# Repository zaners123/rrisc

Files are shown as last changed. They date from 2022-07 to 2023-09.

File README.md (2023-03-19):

# RRISC (Reduced Reduced Instruction Set Computer)

My primary goal for this project was to make a computer from "scratch"
(simple logic gates and memory, no embedded microcontrollers/FPGAs/etc) to learn more about Computer Engineering
as a "learn by doing" approach.

Since it's only made out of simple logic gates and hand-soldered, it needs to be simple in design
(no microcode/pipelining) and in implementation (trying to aim for around 50 logic chips,
none of which are more complex than a comparator).

This project includes the Assembler, LogiSim simulator/emulator, schematic, and PCB.
This is the computer at every level of abstraction, and as such this is Open Source Hardware.

## What is RISC? What does this computer do? 

A RISC computer commonly has simple operations to have higher instructions per second.
My computer has extremely simple operations to have extreme efficiency (ideally).
My goal for this computer is for it to run at about 20MHz.

This is a General Purpose Von-Neumann-Architecture computer with 8-bit instructions.
It has 64Kb of RAM and all 16 instructions follow a quick 3-stage IF/EX/WB cycle.

Instructions are broken up into two parts. Here's the entire **Instruction Set Architecture**:

 ID | Opcode |  Description           |  Argument Type
----|--------|------------------------|-------------------------
 _  | 4 bits | _                      | 4 bits
0x0 | ADD    | Add to R0              | Register(1)
0x1 | ADDI   | Add to R0              | Immediate(2)       
0x2 | SUB    | Subtract from R0       | Register(1)   
0x3 | SUBI   | Subtract from R0       | Immediate(2)  
0x4 | SKIP   | Skip next instruction  | Condition(3)  
0x5 | JUMP   | Jump to MEM            | Condition(3)  
0x6 | XOR    | Xor                    | Register(1)        
0x7 | XORI   | Xor                    | Immediate(2)       
0x8 | AND    | And                    | Register(1)        
0x9 | ANDI   | And                    | Immediate(2)       
0xA | SET    | Move ACC to Reg        | Register(1)
0xB | RB     | Read from memory to Reg| Register(1)
0xC | GET    | Move Reg to ACC        | Register(1)
0xD | WB     | Write from reg to memory|Register(1)
0xE | OR     |                        |
0xF | ORI    |                        |

## Register(1)
The last 4 bits of this argument point to one of the 16 registers.

ACC (AKA R0) is the accumulator register.

R1-RC General Purpose Registers.

RMH,RML point in memory (Register Memory High, Register Memory Low).

RCMP is used in conditional operations<sup>[3](3)</sup>

## Immediate(2)

## Condition(3)

# Assembler

Given an assembly file (Ex: code.asm), it turns it into a hex file (Ex: code.asm.hex) that can be loaded either onto
the real computer, or the simulated computer in LogiSim.

# Simulation

This represents the computer's overall layout. It is both a logical diagram for the computer and a convenient simulator for programs.

Open this with Logisim Evolution. I use "logisim-evolution-3.4.1-all.jar".
Upload the hex from the assembler into the RAM, start the controller, and watch it run!

# Hardware

The strict hardware requirement of this computer is that everything except the memory-mapped-IO has to be made from 7400 logic.

This is made in KiCad, and contains the schematic (local layout of how things connect)
and the PCB design (how to physically connect everything together).

The plan is to have the submodules used in LogiSim (registers, ALU, RAM, etc) be a daughter board for the main PCB.

The plan is to design/order/build the PCBs in this order:
1. Program Counter
    - Logic for jump/skip decisions
2. Registers
    - Might use either a literal register file (select MUX, asynchronous D-latch, 8x 16:1 demux) or a 74xx register file 
3. ALU
4. RAM/ROM/Programmer
5. Motherboard/Controller
6. Memory-Mapped IO
    - Memory Mapped UART
    - Memory Mapped 7-segment Display

This way, I can test them all separately, and revisions can be made more easily.

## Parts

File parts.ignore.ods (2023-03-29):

Name | ID | QTY_HAVE | QTY_MOBO | QTY_ALU | Leftover
NAND | 0 | 9 | 2 | 0 | 7
AND | 8 | 20 | 0 | 3 | 17
? | 14 | 10 | 2 | 0 | 8
AND | 21 | 9 | 0 | 0 | 9
? | 32 | 20 | 3 | 2 | 15
XOR | 86 | 29 | 1 | 4 | 24
? | 137 | 0 | 0 | 0 | 0
3:8DEMUX | 138 | 8 | 1 | 0 | 7
8:1 | 151 | 20 | 1 | 8 | 11
4:1 mux | 153 | 24 | 0 | 0 | 24
4x 2:1MUX | 157 | 20 | 4 | 6 | 10
ShiftReg | 161 | 12 | 4 | 0 | 8
full adder | 283 | 5 | 0 | 2 | 3
reg | 377 | 16 | 1 | 1 | 14
? | 684 | 0 | 0 | 0 | 0

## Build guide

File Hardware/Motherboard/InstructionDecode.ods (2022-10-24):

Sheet: InstructionDecode
Instruction Decoder
 |  |  |  |  | A | B | C | D | E | F | G | H | I | J | K | L | M | N
 | OP[3..0] |  | Name | Decode (OP1,2,3) | Register WE | Swap Nibbles | Imm MSB | R3 | R2 | R1 | R0 | ~CARRY WE / ~L | Out RX ID | Memory Write | Memory Read | OPBIsImm | IsSkip | IsJump
0 | 0000 | 0 | ADD | !D0 | 1 | 0 | x | 1 | 1 | 0 | 0 | 0 | 0 | 0 | 0 | 0 | 0 | 0
1 | 0001 | 1 | ADDI | !D0 | 1 | 0 | 0 | 1 | 1 | 0 | 0 | 0 | 0 | 0 | 0 | 1 | 0 | 0
2 | 0010 | 2 | SUB | !D1 | 1 | 0 | x | 0 | 0 | 1 | 1 | 0 | 0 | 0 | 0 | 0 | 0 | 0
3 | 0011 | 3 | SUBI | !D1 | 1 | 0 | 0 | 0 | 0 | 1 | 1 | 0 | 0 | 0 | 0 | 1 | 0 | 0
4 | 0100 | 4 | SKIP | !D2 | 0 | x | x | x | x | x | x | 1 | x | 0 | 0 | x | 1 | 0
5 | 0101 | 5 | JUMP | !D2 | 0 | x | x | x | x | x | x | 1 | x | 0 | 0 | x | 0 | 1
6 | 0110 | 6 | XOR | !D3 | 1 | 0 | x | 0 | 1 | 1 | 0 | 1 | 0 | 0 | 0 | 0 | 0 | 0
7 | 0111 | 7 | XORI | !D3 | 1 | 1 | 0 | 0 | 1 | 1 | 0 | 1 | 0 | 0 | 0 | 1 | 0 | 0
8 | 1000 | 8 | AND | !D4 | 1 | 0 | x | 1 | 0 | 0 | 0 | 1 | 0 | 0 | 0 | 0 | 0 | 0
9 | 1001 | 9 | ANDI | !D4 | 1 | 1 | 1 | 1 | 0 | 0 | 0 | 1 | 0 | 0 | 0 | 1 | 0 | 0
10 | 1010 | A | SET | !D5 | 1 | 0 | 0 | 1 | 0 | 1 | 0 | 1 | 1 | 0 | 0 | 0 | 0 | 0
11 | 1011 | B | RB | !D5 | 1 | x | x | x | x | x | x | 1 | 1 | 0 | 1 | x | 0 | 0
12 | 1100 | C | GET | !D6 | 1 | 0 | 0 | 1 | 1 | 0 | 0 | 1 | 0 | 0 | 0 | 0 | 0 | 0
13 | 1101 | D | WB | !D6 | 0 | x | x | x | x | x | x | 1 | x | 1 | 0 | x | 0 | 0
14 | 1110 | E | OR | !D7 | 1 | 0 | x | 1 | 1 | 1 | 0 | 1 | 0 | 0 | 0 | 0 | 0 | 0
15 | 1111 | F | ORI | !D7 | 1 | 1 | 0 | 1 | 1 | 1 | 0 | 1 | 0 | 0 | 0 | 1 | 0 | 0
 |  |  |  |  | !D2 ^ J | H&OP0 | D4 | D0|OP3 | D0|OP2 | OP1 | D1 | OP3|OP2 | D5 | D6&OP0 | D5&OP0 | OP0 | !OP0 & D2 | OP0&D2

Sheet: TimingDiagram
 | Last WE is done V | Result on Memory bus | Preform Async Write | Raise WE
Total Time (ns) | 0
Time Delay (ns) | 0 |  | 12
Asynchronous Write |  |  | 1

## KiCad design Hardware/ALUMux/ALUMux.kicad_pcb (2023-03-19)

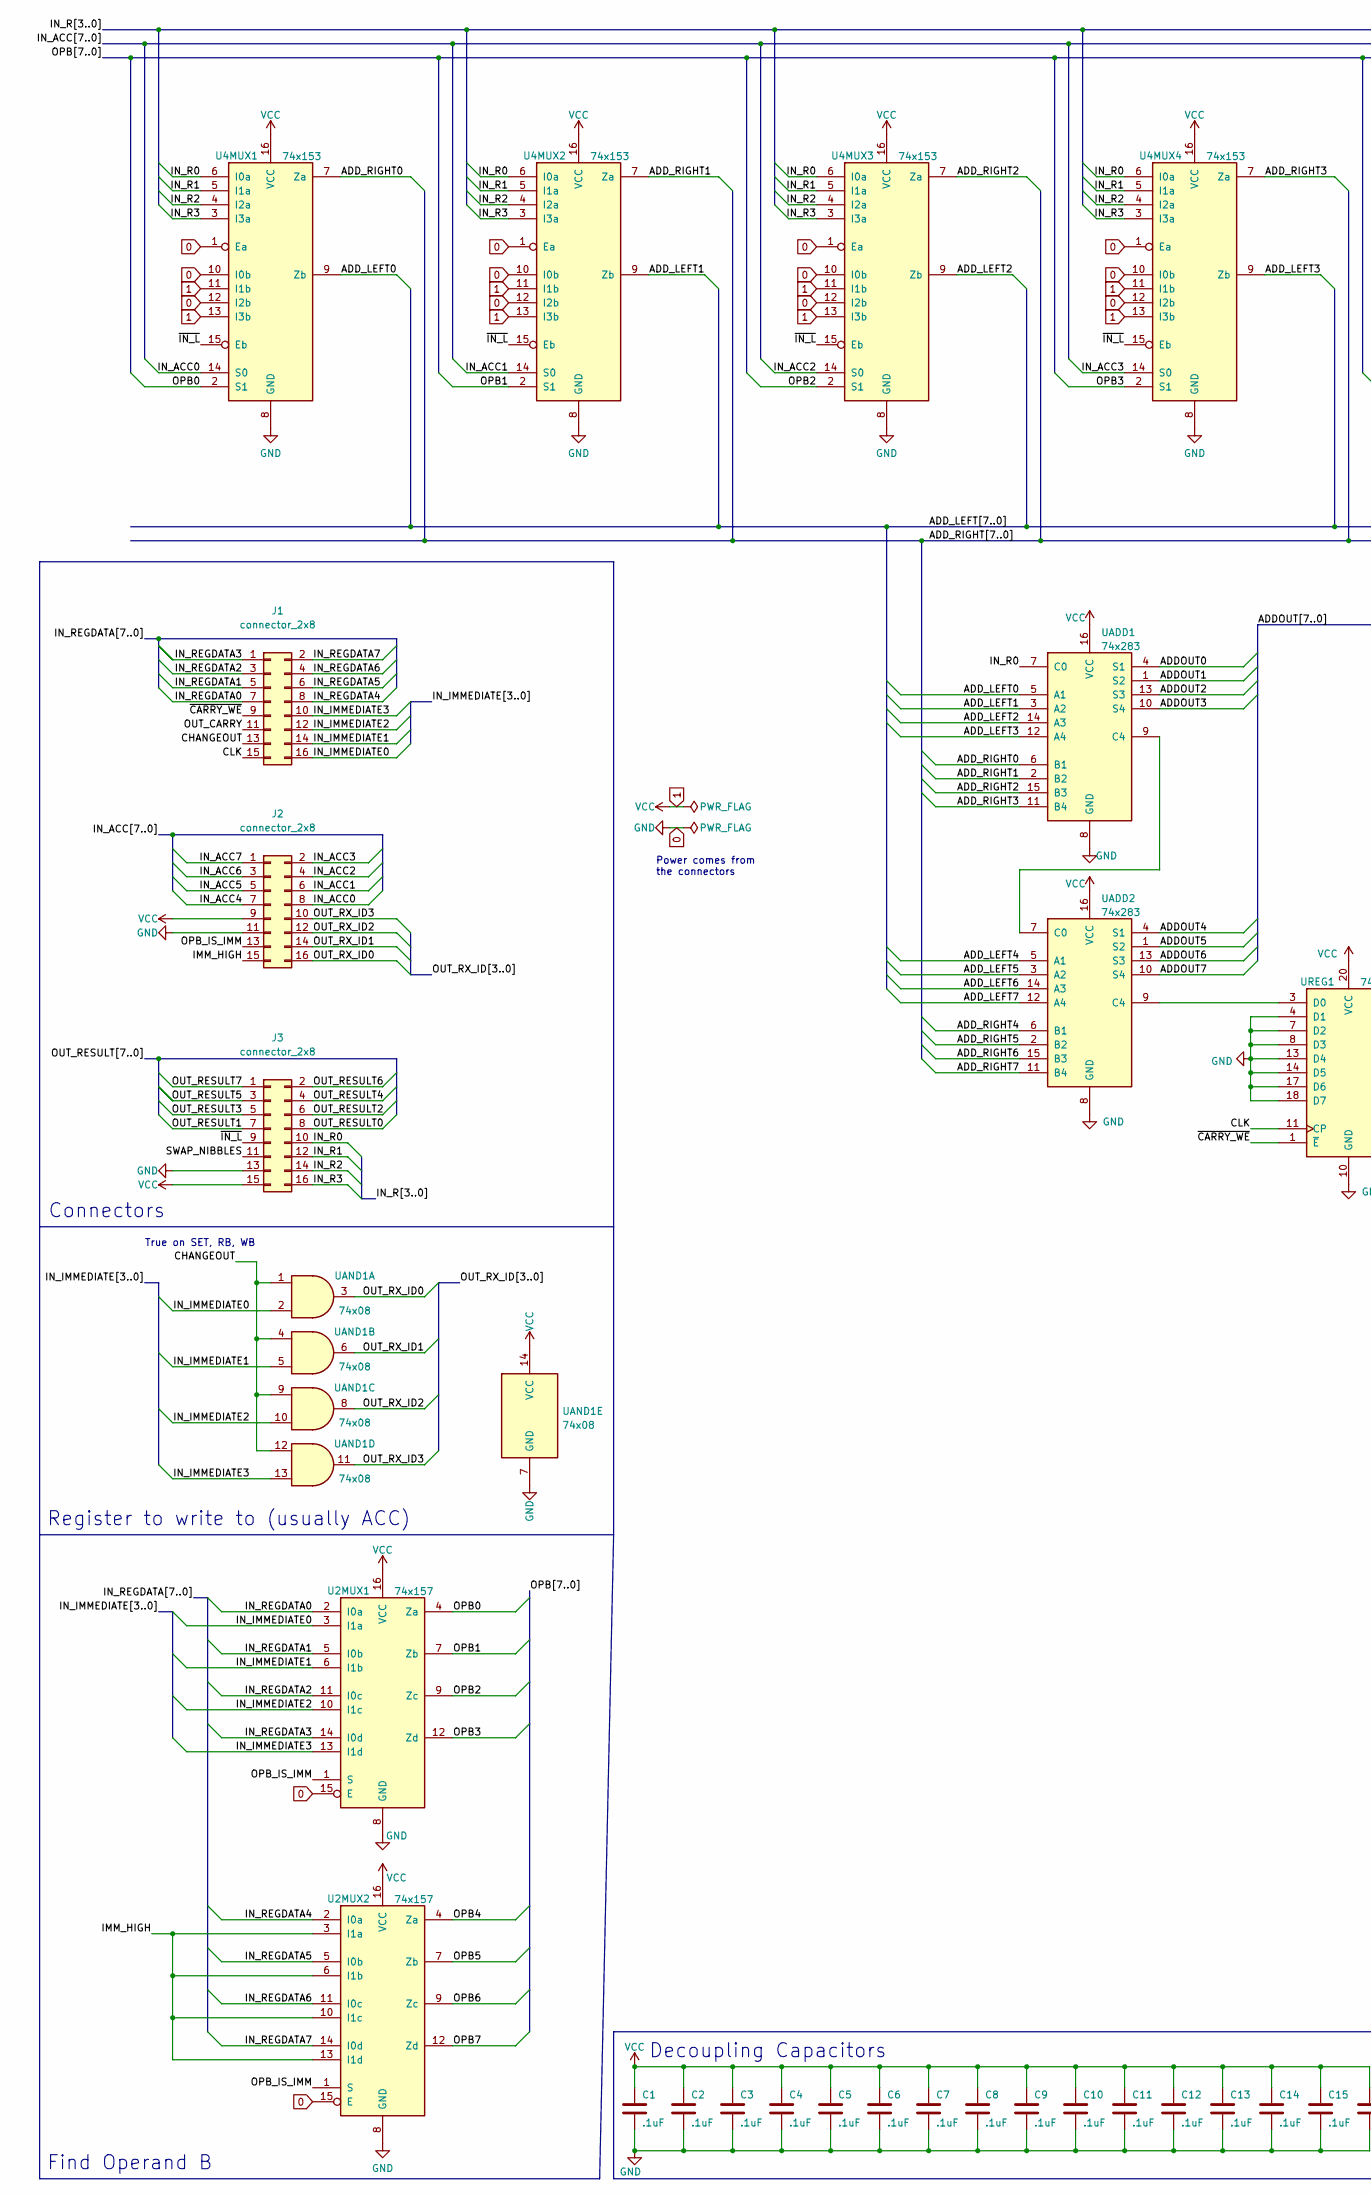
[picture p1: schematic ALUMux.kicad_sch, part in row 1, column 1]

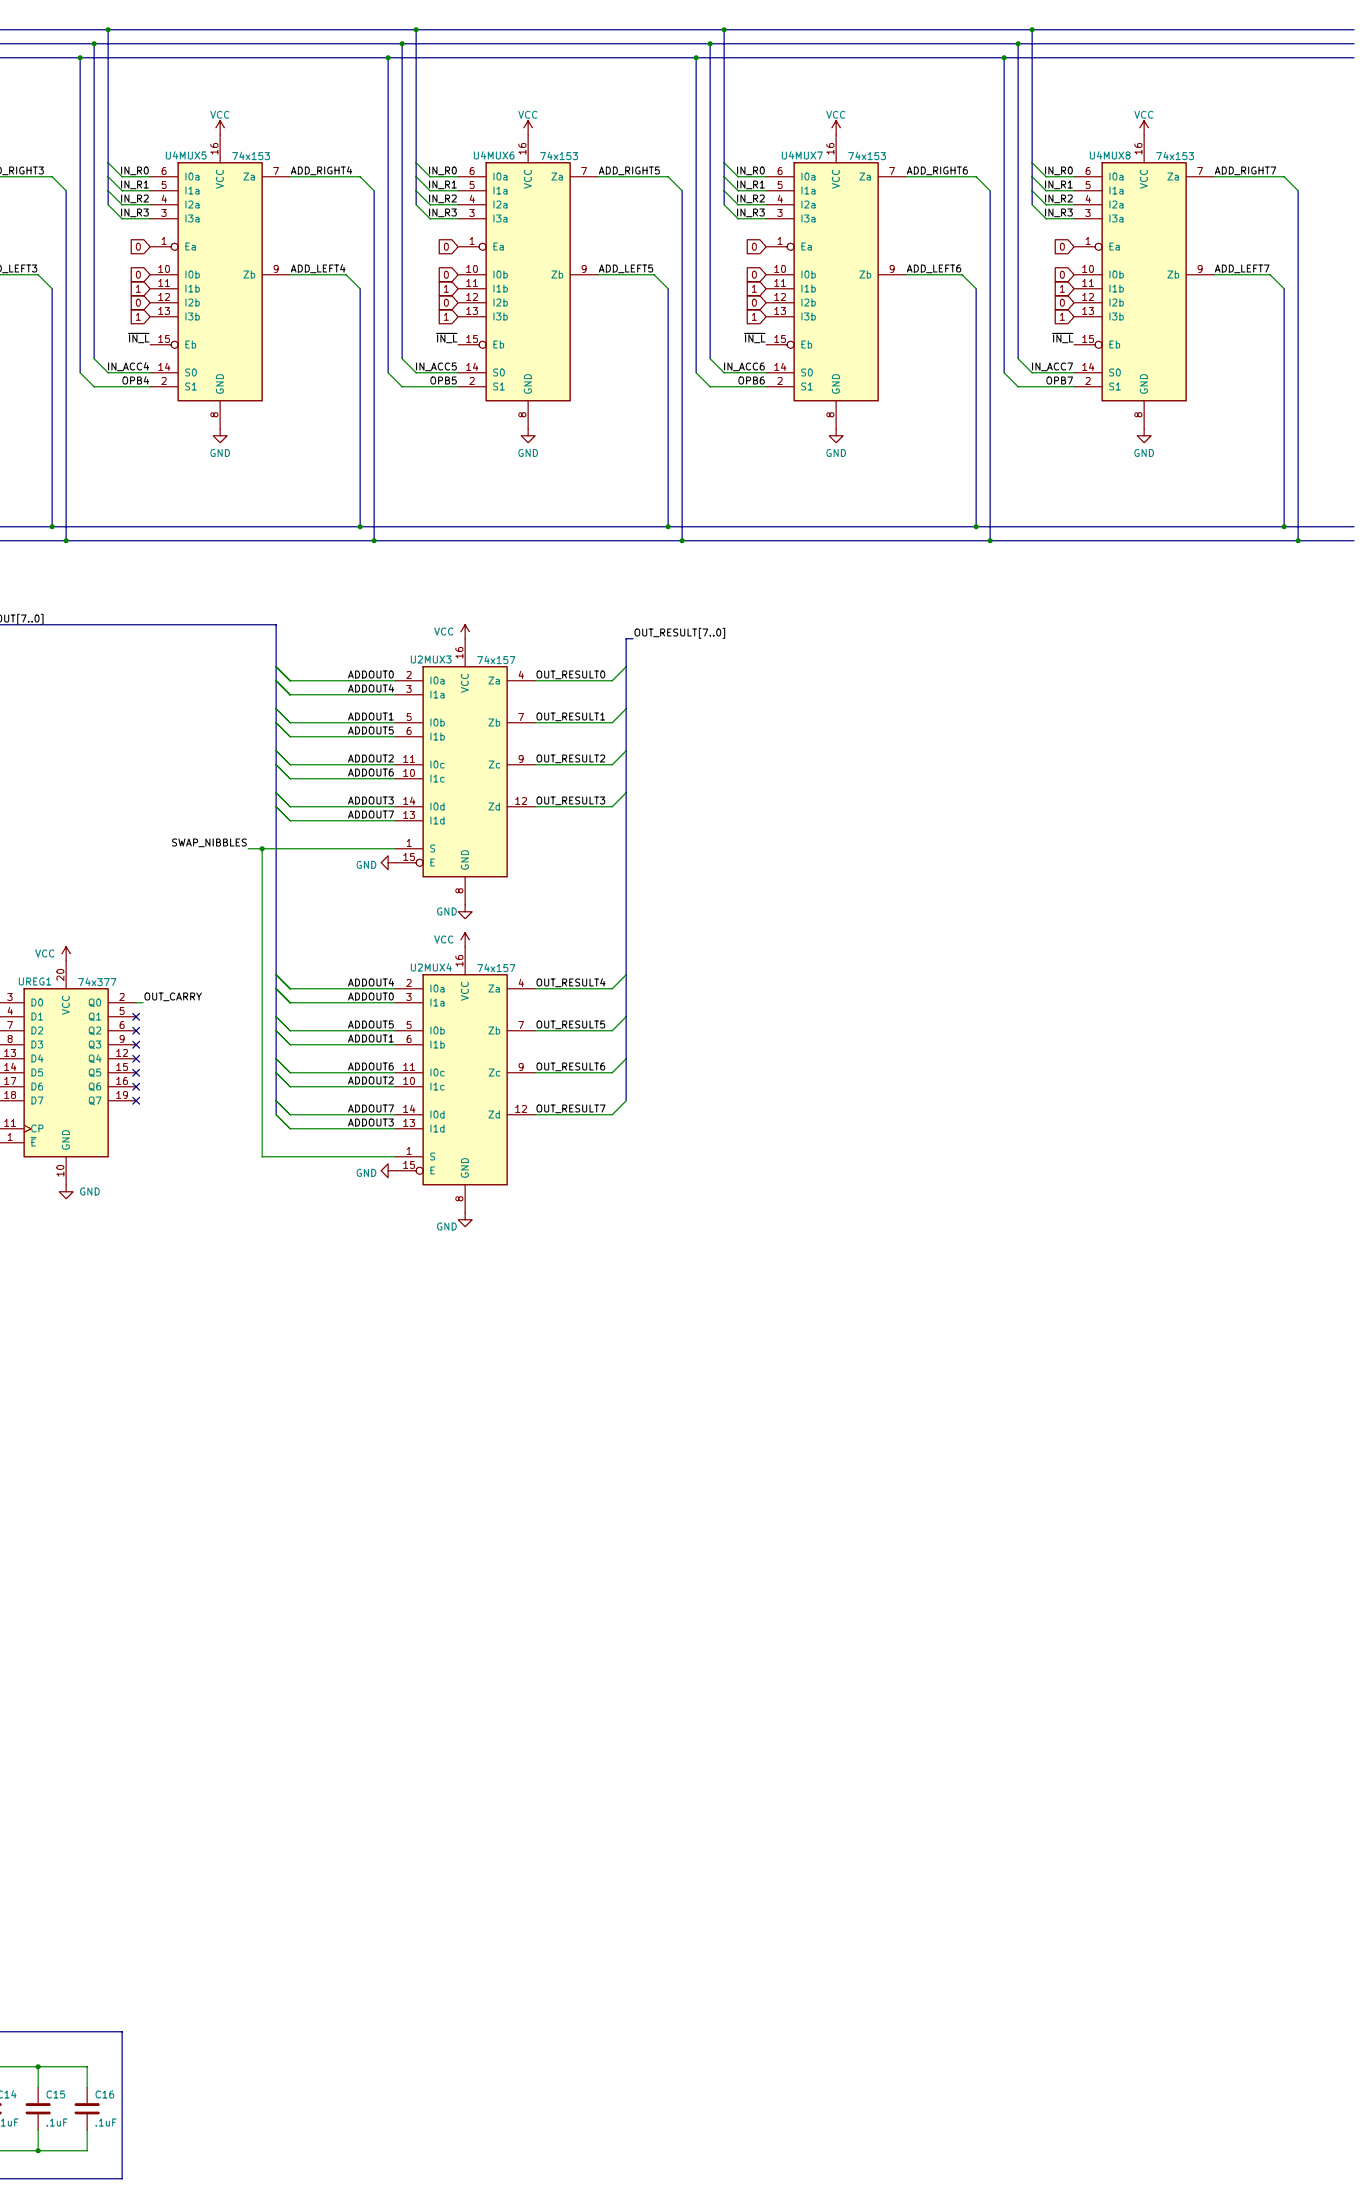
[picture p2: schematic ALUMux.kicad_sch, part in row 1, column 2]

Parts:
C1, C2, C3, C4, C5, C6, C7, C8, C9, C10, C11, C12, C13, C14, C15, C16: .1uF; C_1206_3216Metric_Pad1.33x1.80mm_HandSolder
J1, J2, J3: connector_2x8; PinHeader_2x08_P2.54mm_Horizontal
U2MUX1, U2MUX2, U2MUX3, U2MUX4: 74x157; D_R-PDSO-G16
U4MUX1, U4MUX2, U4MUX3, U4MUX4, U4MUX5, U4MUX6, U4MUX7, U4MUX8: 74x153; D_R-PDSO-G16
UADD1, UADD2: 74x283; D_R-PDSO-G16
UAND1: 74x08; D_R-PDSO-G14
UREG1: 74x377; ON-SOIC20-WB

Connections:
0: C1.2, C2.2, C3.2, C4.2, C5.2, C6.2, C7.2, C8.2, C9.2, C10.2, C11.2, C12.2, C13.2, C14.2, C15.2, C16.2, J2.11, J3.13, U2MUX1.8 (GND), U2MUX1.15 (E), U2MUX2.8 (GND), U2MUX2.15 (E), U2MUX3.8 (GND), U2MUX3.15 (E), U2MUX4.8 (GND), U2MUX4.15 (E), U4MUX1.1 (Ea), U4MUX1.8 (GND), U4MUX1.10 (I0b), U4MUX1.12 (I2b), U4MUX2.1 (Ea), U4MUX2.8 (GND), U4MUX2.10 (I0b), U4MUX2.12 (I2b), U4MUX3.1 (Ea), U4MUX3.8 (GND), U4MUX3.10 (I0b), U4MUX3.12 (I2b), U4MUX4.1 (Ea), U4MUX4.8 (GND), U4MUX4.10 (I0b), U4MUX4.12 (I2b), U4MUX5.1 (Ea), U4MUX5.8 (GND), U4MUX5.10 (I0b), U4MUX5.12 (I2b), U4MUX6.1 (Ea), U4MUX6.8 (GND), U4MUX6.10 (I0b), U4MUX6.12 (I2b), U4MUX7.1 (Ea), U4MUX7.8 (GND), U4MUX7.10 (I0b), U4MUX7.12 (I2b), U4MUX8.1 (Ea), U4MUX8.8 (GND), U4MUX8.10 (I0b), U4MUX8.12 (I2b), UADD1.8 (GND), UADD2.8 (GND), UAND1.7 (GND), UREG1.4 (D1), UREG1.7 (D2), UREG1.8 (D3), UREG1.10 (GND), UREG1.13 (D4), UREG1.14 (D5), UREG1.17 (D6), UREG1.18 (D7)
1: C1.1, C2.1, C3.1, C4.1, C5.1, C6.1, C7.1, C8.1, C9.1, C10.1, C11.1, C12.1, C13.1, C14.1, C15.1, C16.1, J2.9, J3.15, U2MUX1.16 (VCC), U2MUX2.16 (VCC), U2MUX3.16 (VCC), U2MUX4.16 (VCC), U4MUX1.11 (I1b), U4MUX1.13 (I3b), U4MUX1.16 (VCC), U4MUX2.11 (I1b), U4MUX2.13 (I3b), U4MUX2.16 (VCC), U4MUX3.11 (I1b), U4MUX3.13 (I3b), U4MUX3.16 (VCC), U4MUX4.11 (I1b), U4MUX4.13 (I3b), U4MUX4.16 (VCC), U4MUX5.11 (I1b), U4MUX5.13 (I3b), U4MUX5.16 (VCC), U4MUX6.11 (I1b), U4MUX6.13 (I3b), U4MUX6.16 (VCC), U4MUX7.11 (I1b), U4MUX7.13 (I3b), U4MUX7.16 (VCC), U4MUX8.11 (I1b), U4MUX8.13 (I3b), U4MUX8.16 (VCC), UADD1.16 (VCC), UADD2.16 (VCC), UAND1.14 (VCC), UREG1.20 (VCC)
/ADDOUT0: U2MUX3.2 (I0a), U2MUX4.3 (I1a), UADD1.4 (S1)
/ADDOUT1: U2MUX3.5 (I0b), U2MUX4.6 (I1b), UADD1.1 (S2)
/ADDOUT2: U2MUX3.11 (I0c), U2MUX4.10 (I1c), UADD1.13 (S3)
/ADDOUT3: U2MUX3.14 (I0d), U2MUX4.13 (I1d), UADD1.10 (S4)
/ADDOUT4: U2MUX3.3 (I1a), U2MUX4.2 (I0a), UADD2.4 (S1)
/ADDOUT5: U2MUX3.6 (I1b), U2MUX4.5 (I0b), UADD2.1 (S2)
/ADDOUT6: U2MUX3.10 (I1c), U2MUX4.11 (I0c), UADD2.13 (S3)
/ADDOUT7: U2MUX3.13 (I1d), U2MUX4.14 (I0d), UADD2.10 (S4)
/ADD_LEFT0: U4MUX1.9 (Zb), UADD1.5 (A1)
/ADD_LEFT1: U4MUX2.9 (Zb), UADD1.3 (A2)
/ADD_LEFT2: U4MUX3.9 (Zb), UADD1.14 (A3)
/ADD_LEFT3: U4MUX4.9 (Zb), UADD1.12 (A4)
/ADD_LEFT4: U4MUX5.9 (Zb), UADD2.5 (A1)
/ADD_LEFT5: U4MUX6.9 (Zb), UADD2.3 (A2)
/ADD_LEFT6: U4MUX7.9 (Zb), UADD2.14 (A3)
/ADD_LEFT7: U4MUX8.9 (Zb), UADD2.12 (A4)
/ADD_RIGHT0: U4MUX1.7 (Za), UADD1.6 (B1)
/ADD_RIGHT1: U4MUX2.7 (Za), UADD1.2 (B2)
/ADD_RIGHT2: U4MUX3.7 (Za), UADD1.15 (B3)
/ADD_RIGHT3: U4MUX4.7 (Za), UADD1.11 (B4)
/ADD_RIGHT4: U4MUX5.7 (Za), UADD2.6 (B1)
/ADD_RIGHT5: U4MUX6.7 (Za), UADD2.2 (B2)
/ADD_RIGHT6: U4MUX7.7 (Za), UADD2.15 (B3)
/ADD_RIGHT7: U4MUX8.7 (Za), UADD2.11 (B4)
/CHANGEOUT: J1.13, UAND1.1, UAND1.4, UAND1.9, UAND1.12
/CLK: J1.15, UREG1.11 (CP)
/IMM_HIGH: J2.15, U2MUX2.3 (I1a), U2MUX2.6 (I1b), U2MUX2.10 (I1c), U2MUX2.13 (I1d)
/IN_ACC0: J2.8, U4MUX1.14 (S0)
/IN_ACC1: J2.6, U4MUX2.14 (S0)
/IN_ACC2: J2.4, U4MUX3.14 (S0)
/IN_ACC3: J2.2, U4MUX4.14 (S0)
/IN_ACC4: J2.7, U4MUX5.14 (S0)
/IN_ACC5: J2.5, U4MUX6.14 (S0)
/IN_ACC6: J2.3, U4MUX7.14 (S0)
/IN_ACC7: J2.1, U4MUX8.14 (S0)
/IN_IMMEDIATE0: J1.16, U2MUX1.3 (I1a), UAND1.2
/IN_IMMEDIATE1: J1.14, U2MUX1.6 (I1b), UAND1.5
/IN_IMMEDIATE2: J1.12, U2MUX1.10 (I1c), UAND1.10
/IN_IMMEDIATE3: J1.10, U2MUX1.13 (I1d), UAND1.13
/IN_R0: J3.10, U4MUX1.6 (I0a), U4MUX2.6 (I0a), U4MUX3.6 (I0a), U4MUX4.6 (I0a), U4MUX5.6 (I0a), U4MUX6.6 (I0a), U4MUX7.6 (I0a), U4MUX8.6 (I0a), UADD1.7 (C0)
/IN_R1: J3.12, U4MUX1.5 (I1a), U4MUX2.5 (I1a), U4MUX3.5 (I1a), U4MUX4.5 (I1a), U4MUX5.5 (I1a), U4MUX6.5 (I1a), U4MUX7.5 (I1a), U4MUX8.5 (I1a)
/IN_R2: J3.14, U4MUX1.4 (I2a), U4MUX2.4 (I2a), U4MUX3.4 (I2a), U4MUX4.4 (I2a), U4MUX5.4 (I2a), U4MUX6.4 (I2a), U4MUX7.4 (I2a), U4MUX8.4 (I2a)
/IN_R3: J3.16, U4MUX1.3 (I3a), U4MUX2.3 (I3a), U4MUX3.3 (I3a), U4MUX4.3 (I3a), U4MUX5.3 (I3a), U4MUX6.3 (I3a), U4MUX7.3 (I3a), U4MUX8.3 (I3a)
/IN_REGDATA0: J1.7, U2MUX1.2 (I0a)
/IN_REGDATA1: J1.5, U2MUX1.5 (I0b)
/IN_REGDATA2: J1.3, U2MUX1.11 (I0c)
/IN_REGDATA3: J1.1, U2MUX1.14 (I0d)
/IN_REGDATA4: J1.8, U2MUX2.2 (I0a)
/IN_REGDATA5: J1.6, U2MUX2.5 (I0b)
/IN_REGDATA6: J1.4, U2MUX2.11 (I0c)
/IN_REGDATA7: J1.2, U2MUX2.14 (I0d)
/OPB0: U2MUX1.4 (Za), U4MUX1.2 (S1)
/OPB1: U2MUX1.7 (Zb), U4MUX2.2 (S1)
/OPB2: U2MUX1.9 (Zc), U4MUX3.2 (S1)
/OPB3: U2MUX1.12 (Zd), U4MUX4.2 (S1)
/OPB4: U2MUX2.4 (Za), U4MUX5.2 (S1)
/OPB5: U2MUX2.7 (Zb), U4MUX6.2 (S1)
/OPB6: U2MUX2.9 (Zc), U4MUX7.2 (S1)
/OPB7: U2MUX2.12 (Zd), U4MUX8.2 (S1)
/OPB_IS_IMM: J2.13, U2MUX1.1 (S), U2MUX2.1 (S)
/OUT_CARRY: J1.11, UREG1.2 (Q0)
/OUT_RESULT0: J3.8, U2MUX3.4 (Za)
/OUT_RESULT1: J3.7, U2MUX3.7 (Zb)
/OUT_RESULT2: J3.6, U2MUX3.9 (Zc)
/OUT_RESULT3: J3.5, U2MUX3.12 (Zd)
/OUT_RESULT4: J3.4, U2MUX4.4 (Za)
/OUT_RESULT5: J3.3, U2MUX4.7 (Zb)
/OUT_RESULT6: J3.2, U2MUX4.9 (Zc)
/OUT_RESULT7: J3.1, U2MUX4.12 (Zd)
/OUT_RX_ID0: J2.16, UAND1.3
/OUT_RX_ID1: J2.14, UAND1.6
/OUT_RX_ID2: J2.12, UAND1.8
/OUT_RX_ID3: J2.10, UAND1.11
/SWAP_NIBBLES: J3.11, U2MUX3.1 (S), U2MUX4.1 (S)
/~CARRY_WE: J1.9, UREG1.1 (~E)
/~IN_L: J3.9, U4MUX1.15 (Eb), U4MUX2.15 (Eb), U4MUX3.15 (Eb), U4MUX4.15 (Eb), U4MUX5.15 (Eb), U4MUX6.15 (Eb), U4MUX7.15 (Eb), U4MUX8.15 (Eb)
unnamed: UADD1.9 (C4), UADD2.7 (C0)
unnamed: UADD2.9 (C4), UREG1.3 (D0)

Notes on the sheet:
Connectors
True on SET, RB, WB
Register to write to (usually ACC)
Power comes from the connectors
Find Operand B
Decoupling Capacitors

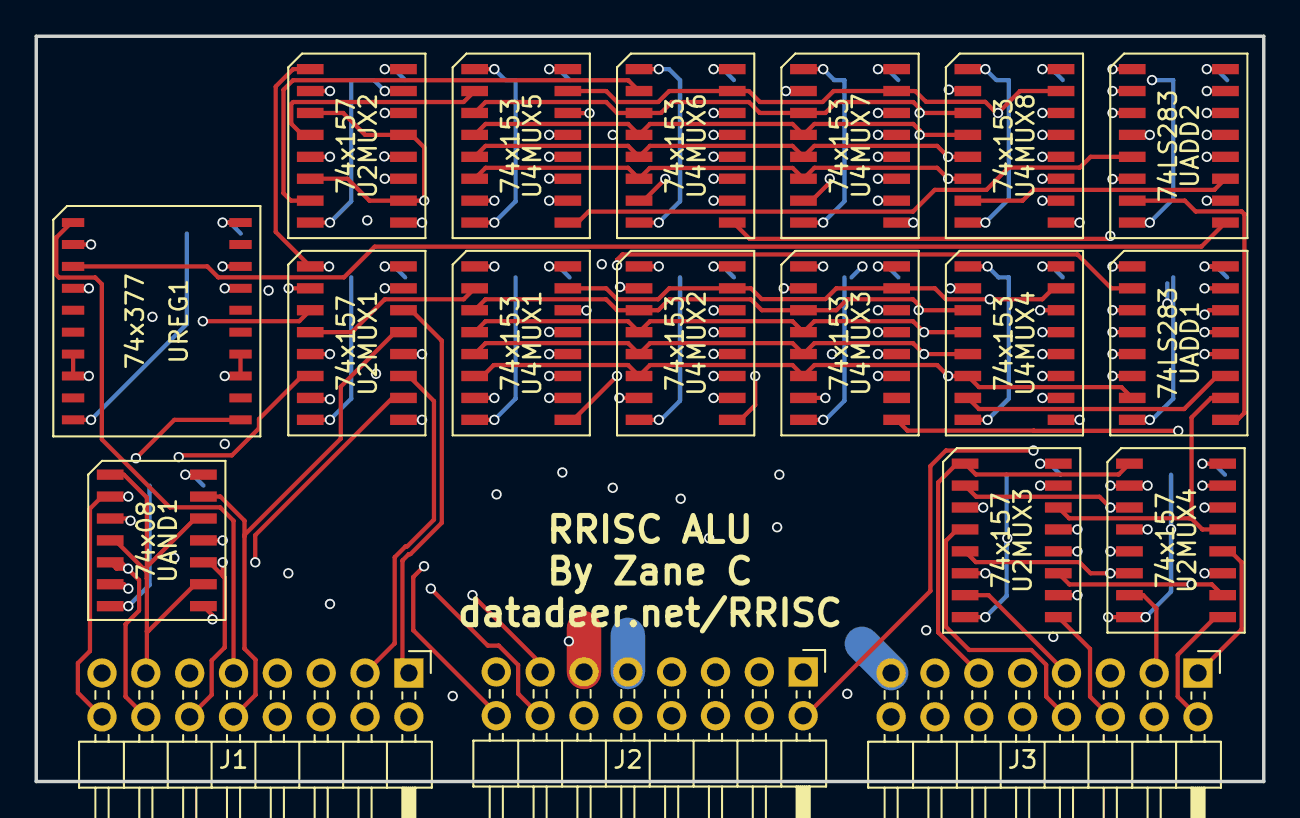
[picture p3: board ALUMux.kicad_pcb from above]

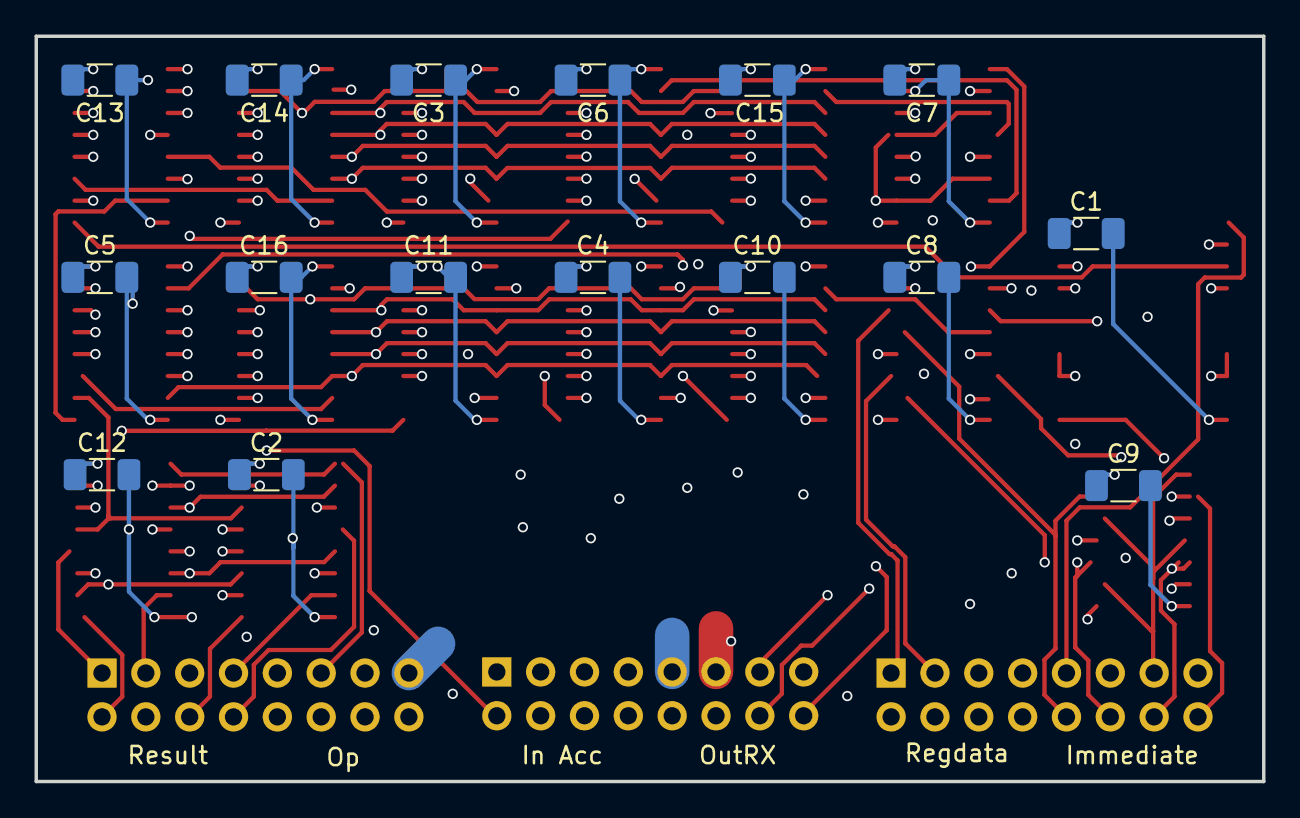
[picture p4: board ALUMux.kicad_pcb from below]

Board: 4 copper layers, 71.1 x 43.2 mm, 35 parts (16 on the bottom side), 80 nets.

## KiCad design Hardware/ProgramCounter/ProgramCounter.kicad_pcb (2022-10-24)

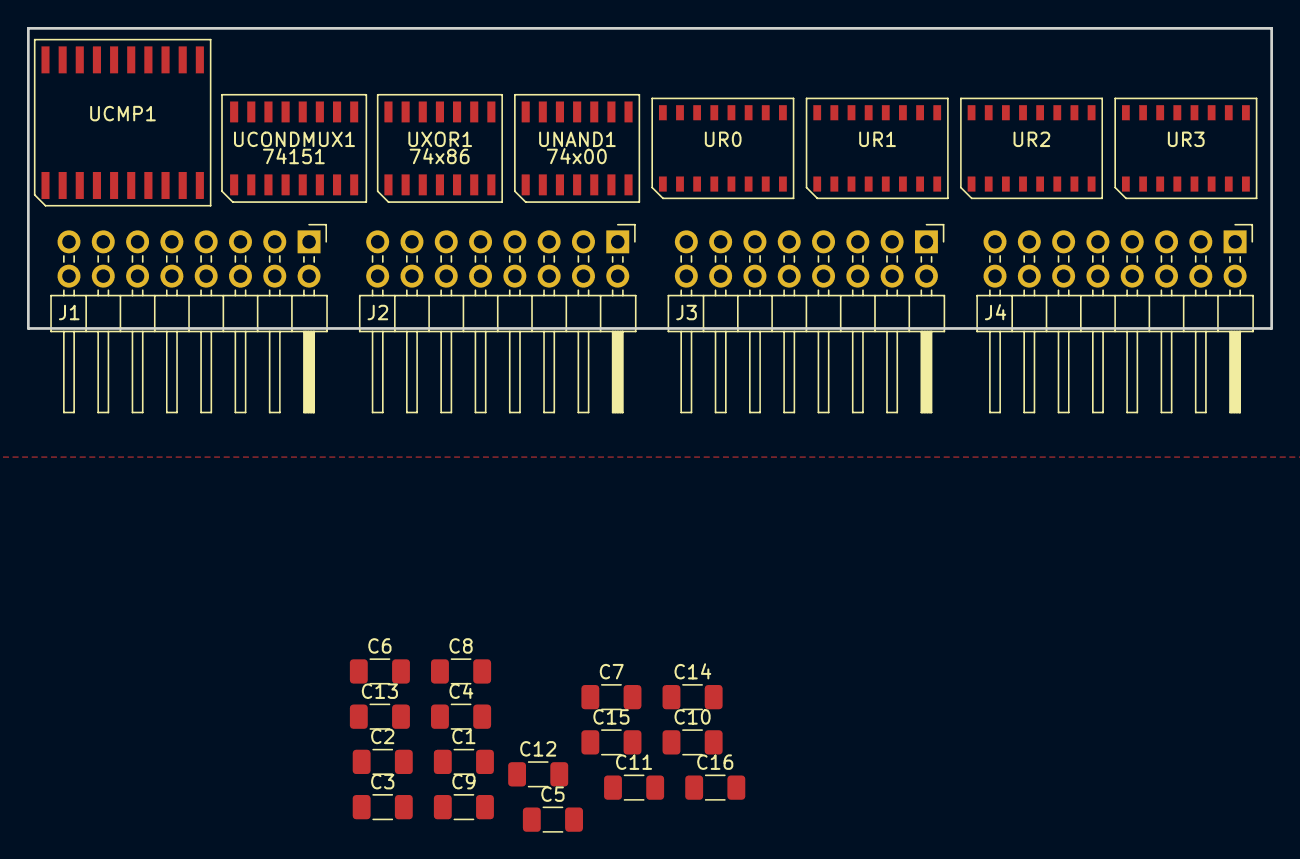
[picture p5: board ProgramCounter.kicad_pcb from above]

Board: 4 copper layers, 92.1 x 22.2 mm, 28 parts (0 on the bottom side), 70 nets, no tracks yet.

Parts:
C1, C2, C3, C4, C5, C6, C7, C8, C9, C10, C11, C12, C13, C14, C15, C16: .1uF; C_1206_3216Metric_Pad1.33x1.80mm_HandSolder
J1, J2, J3, J4: Conn_02x08; PinHeader_2x08_P2.54mm_Horizontal
UCMP1: 74LS684; SOIC20_TI_DW0020A
UCONDMUX1: 74151; D_R-PDSO-G16
UNAND1: 74x00; D_R-PDSO-G14
UR0, UR1, UR2, UR3: 74LS161; SOIC16-ONSEMI_751B-05_K
UXOR1: 74x86; D_R-PDSO-G14

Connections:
/CARRY0: UR0.15 (TC), UR1.10 (CET)
/CARRY1: UR1.15 (TC), UR2.10 (CET)
/CARRY2: UR2.15 (TC), UR3.10 (CET)
/CEP: J2.16, UR0.7 (CEP), UR1.7 (CEP), UR2.7 (CEP), UR3.7 (CEP)
/CLK_WB: J2.8, UR0.2 (CP), UR1.2 (CP), UR2.2 (CP), UR3.2 (CP)
/FLAG_CARRY: J2.11, UCONDMUX1.12 (I7)
/IMM0: J2.3, UXOR1.1
/IMM1: J2.5, UCONDMUX1.11 (S0)
/IMM2: J2.7, UCONDMUX1.10 (S1)
/IMM3: J2.9, UCONDMUX1.9 (S2)
/IS_SKIP: J2.10, UNAND1.8
/JINST: J2.14, UNAND1.13
/PCEVENT: UNAND1.4, UNAND1.12, UXOR1.3
/PCOUT0: J3.16, UR0.14 (Q0)
/PCOUT1: J3.14, UR0.13 (Q1)
/PCOUT2: J3.12, UR0.12 (Q2)
/PCOUT3: J3.10, UR0.11 (Q3)
/PCOUT4: J3.8, UR1.14 (Q0)
/PCOUT5: J3.6, UR1.13 (Q1)
/PCOUT6: J3.4, UR1.12 (Q2)
/PCOUT7: J3.2, UR1.11 (Q3)
/PCOUT8: J4.16, UR2.14 (Q0)
/PCOUT9: J4.14, UR2.13 (Q1)
/PCOUT10: J4.12, UR2.12 (Q2)
/PCOUT11: J4.10, UR2.11 (Q3)
/PCOUT12: J4.8, UR3.14 (Q0)
/PCOUT13: J4.6, UR3.13 (Q1)
/PCOUT14: J4.4, UR3.12 (Q2)
/PCOUT15: J4.2, UR3.11 (Q3)
/RCD0: J1.1, UCMP1.3 (Q0)
/RCD1: J1.3, UCMP1.5 (Q1)
/RCD2: J1.5, UCMP1.7 (Q2)
/RCD3: J1.7, UCMP1.9 (Q3)
/RCD4: J1.9, UCMP1.12 (Q4)
/RCD5: J1.11, UCMP1.14 (Q5)
/RCD6: J1.13, UCMP1.16 (Q6)
/RCD7: J1.15, UCMP1.18 (Q7)
/RCS0: J1.2, UCMP1.2 (P0), UCONDMUX1.13 (I6)
/RCS1: J1.4, UCMP1.4 (P1)
/RCS2: J1.6, UCMP1.6 (P2)
/RCS3: J1.8, UCMP1.8 (P3)
/RCS4: J1.10, UCMP1.11 (P4)
/RCS5: J1.12, UCMP1.13 (P5)
/RCS6: J1.14, UCMP1.15 (P6)
/RCS7: J1.16, UCMP1.17 (P7), UCONDMUX1.2 (I2)
/REGMEM0: J3.15, UR0.3 (D0)
/REGMEM1: J3.13, UR0.4 (D1)
/REGMEM2: J3.11, UR0.5 (D2)
/REGMEM3: J3.9, UR0.6 (D3)
/REGMEM4: J3.7, UR1.3 (D0)
/REGMEM5: J3.5, UR1.4 (D1)
/REGMEM6: J3.3, UR1.5 (D2)
/REGMEM7: J3.1, UR1.6 (D3)
/REGMEM8: J4.15, UR2.3 (D0)
/REGMEM9: J4.13, UR2.4 (D1)
/REGMEM10: J4.11, UR2.5 (D2)
/REGMEM11: J4.9, UR2.6 (D3)
/REGMEM12: J4.7, UR3.3 (D0)
/REGMEM13: J4.5, UR3.4 (D1)
/REGMEM14: J4.3, UR3.5 (D2)
/REGMEM15: J4.1, UR3.6 (D3)
/SINST: J2.12, UNAND1.5
/cmpeq: UCMP1.19 (~P=Q), UCONDMUX1.15 (I4), UNAND1.1
/cmpgt: UCMP1.1 (~P>Q), UCONDMUX1.1 (I3), UNAND1.2
/~IS_JMP: UNAND1.11, UR0.9 (~PE), UR1.9 (~PE), UR2.9 (~PE), UR3.9 (~PE)
/~IS_SKIP: UNAND1.6, UNAND1.9
/~RST: J2.6, UR0.1 (~MR), UR1.1 (~MR), UR2.1 (~MR), UR3.1 (~MR)
GND: C1.2, C2.2, C3.2, C4.2, C5.2, C6.2, C7.2, C8.2, C9.2, C10.2, C11.2, C12.2, C13.2, C14.2, C15.2, C16.2, J2.1, J2.2, J2.15, UCMP1.10 (Gnd), UCONDMUX1.4 (I0), UCONDMUX1.7 (~E), UCONDMUX1.8 (GND), UNAND1.7 (GND), UR0.8 (GND), UR1.8 (GND), UR2.8 (GND), UR3.8 (GND), UXOR1.4, UXOR1.5, UXOR1.7 (GND), UXOR1.9, UXOR1.10, UXOR1.12, UXOR1.13
unnamed: UCONDMUX1.5 (Q), UXOR1.2
VCC: C1.1, C2.1, C3.1, C4.1, C5.1, C6.1, C7.1, C8.1, C9.1, C10.1, C11.1, C12.1, C13.1, C14.1, C15.1, C16.1, J2.4, J2.13, UCMP1.20 (Vcc), UCONDMUX1.16 (VCC), UNAND1.10, UNAND1.14 (VCC), UR0.10 (CET), UR0.16 (VCC), UR1.16 (VCC), UR2.16 (VCC), UR3.16 (VCC), UXOR1.14 (VCC)

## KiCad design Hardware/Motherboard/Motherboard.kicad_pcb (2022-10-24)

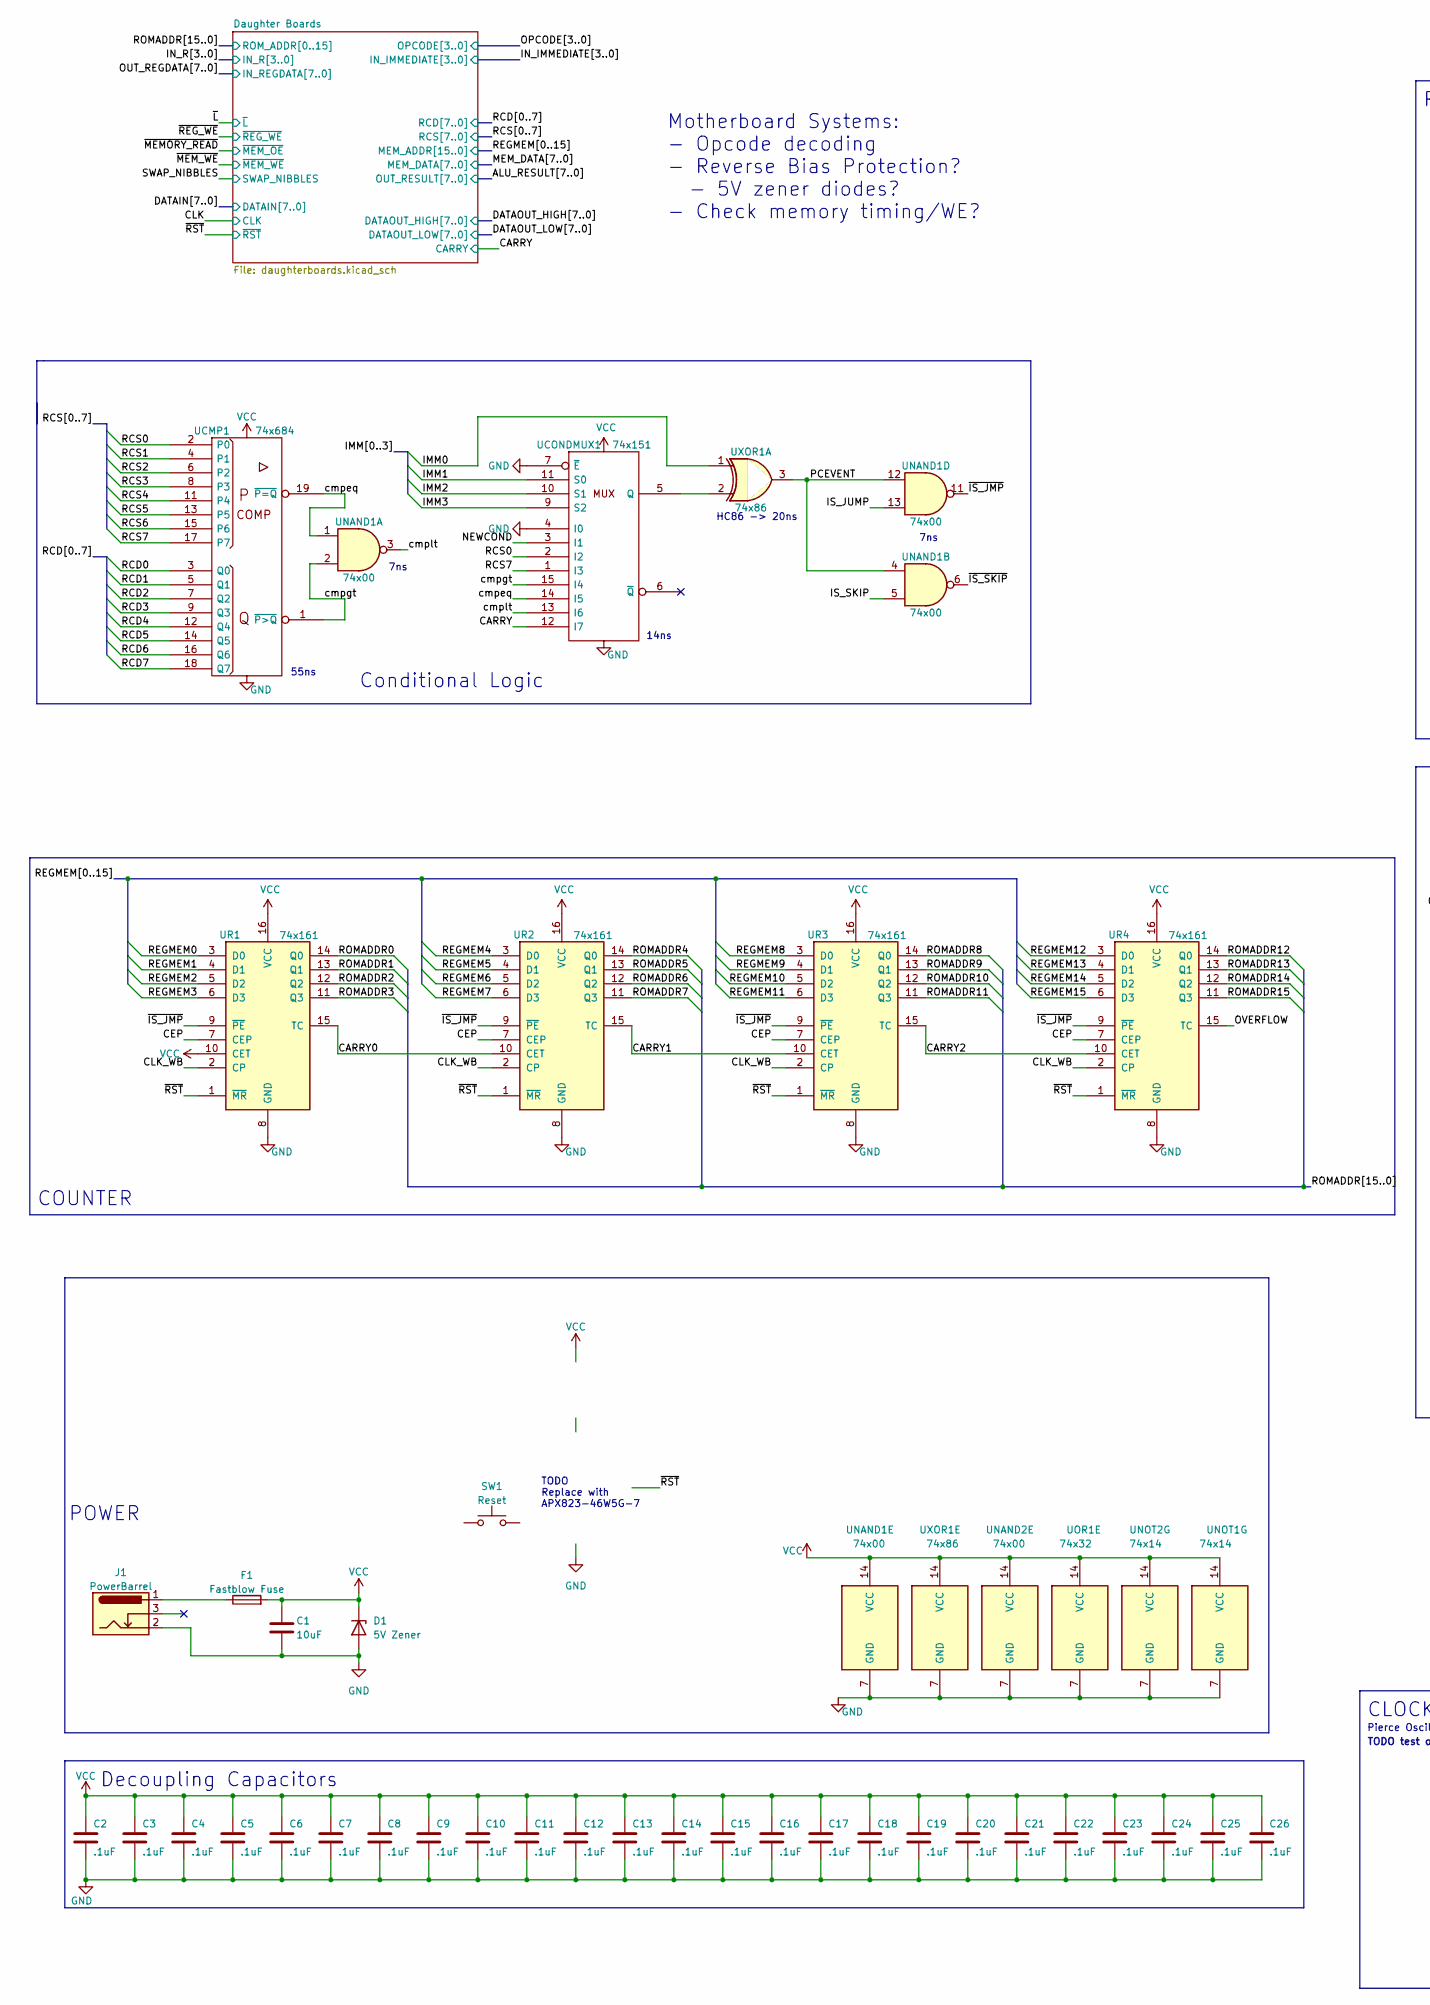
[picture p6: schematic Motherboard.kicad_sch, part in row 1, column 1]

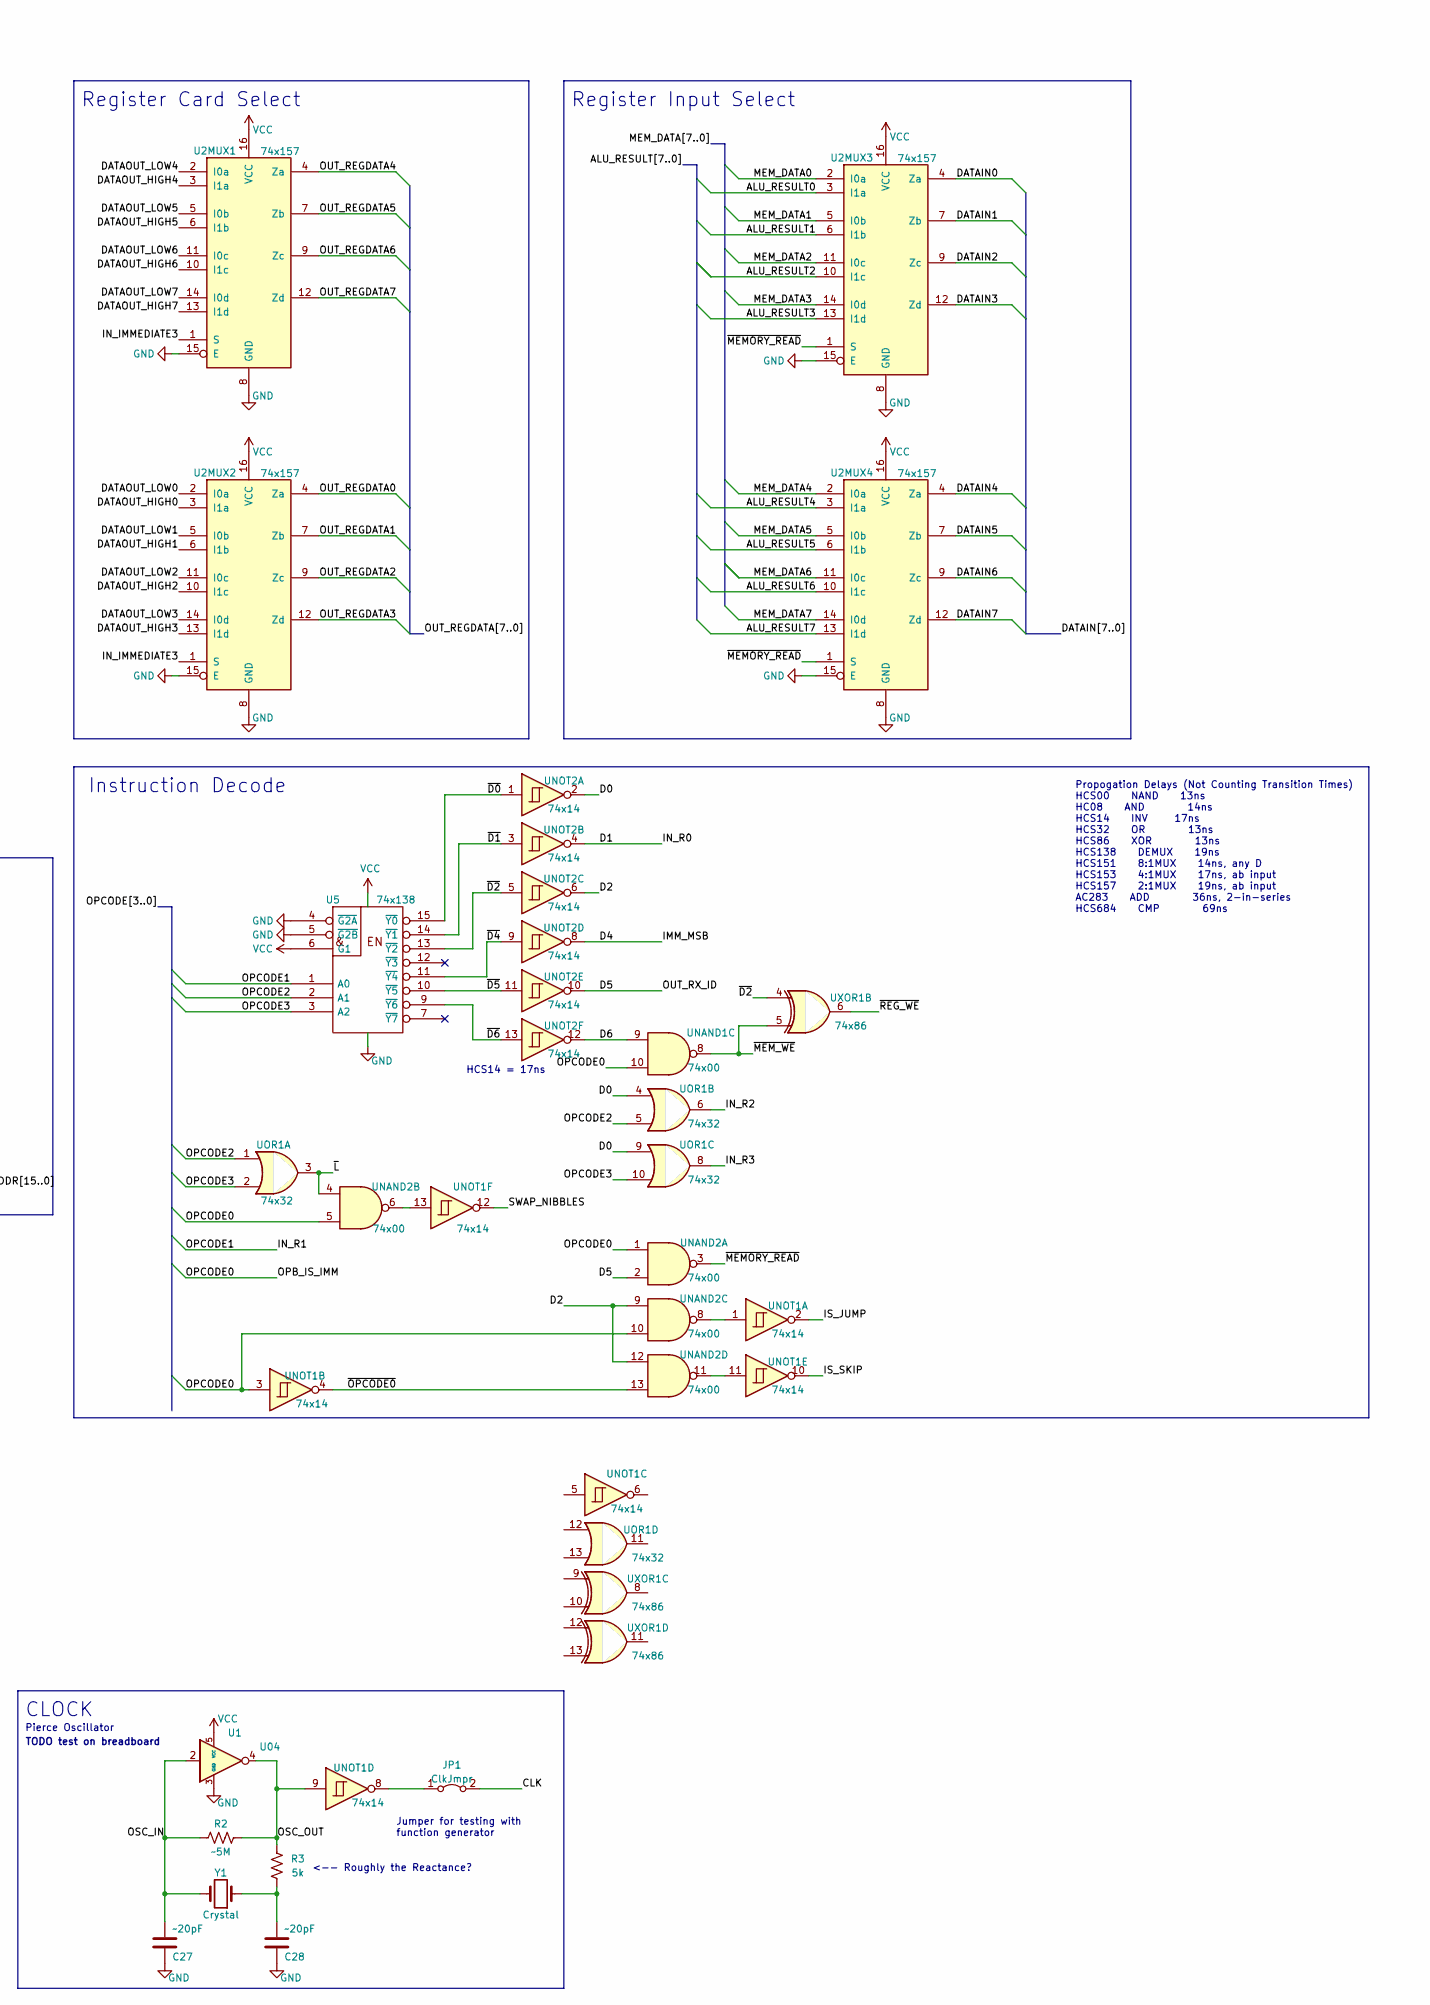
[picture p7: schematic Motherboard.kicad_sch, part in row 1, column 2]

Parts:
C1: 10uF; C_1206_3216Metric_Pad1.33x1.80mm_HandSolder
C2, C3, C4, C5, C6, C7, C8, C9, C10, C11, C12, C13, C14, C15, C16, C17, C18, C19, C20, C21, C22, C23, C24, C25, C26: .1uF; C_1206_3216Metric_Pad1.33x1.80mm_HandSolder
C27, C28: ~20pF; C_Disc_D5.0mm_W2.5mm_P2.50mm
D1: 5V Zener
F1: Fastblow Fuse
J1: PowerBarrel; BarrelJack_Horizontal
JP1: ClkJmpr; PinHeader_1x02_P2.54mm_Vertical
R2: ~5M; R_1206_3216Metric_Pad1.30x1.75mm_HandSolder
R3: 5k; R_1206_3216Metric_Pad1.30x1.75mm_HandSolder
SW1: Reset; SW_PUSH_6mm_H5mm
U1: U04; TSOP5-CASE483
U2MUX1, U2MUX2, U2MUX3, U2MUX4: 74x157; D_R-PDSO-G16
U5: 74x138; R-PDSO-G16
UCMP1: 74x684; SOIC20_TI_DW0020A
UCONDMUX1: 74x151; D_R-PDSO-G16
UNAND1, UNAND2: 74x00; D_R-PDSO-G14
UNOT1, UNOT2: 74x14; D_R-PDSO-G14
UOR1: 74x32; D_R-PDSO-G14
UR1, UR2, UR3, UR4: 74x161; SOIC16-ONSEMI_751B-05_K
UXOR1: 74x86; D_R-PDSO-G14
Y1: Crystal; Crystal_HC49-4H_Vertical

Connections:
/ALU_RESULT0: U2MUX3.3 (I1a); also elsewhere on the board
/ALU_RESULT1: U2MUX3.6 (I1b); also elsewhere on the board
/ALU_RESULT2: U2MUX3.10 (I1c); also elsewhere on the board
/ALU_RESULT3: U2MUX3.13 (I1d); also elsewhere on the board
/ALU_RESULT4: U2MUX4.3 (I1a); also elsewhere on the board
/ALU_RESULT5: U2MUX4.6 (I1b); also elsewhere on the board
/ALU_RESULT6: U2MUX4.10 (I1c); also elsewhere on the board
/ALU_RESULT7: U2MUX4.13 (I1d); also elsewhere on the board
/CARRY0: UR1.15 (TC), UR2.10 (CET)
/CARRY1: UR2.15 (TC), UR3.10 (CET)
/CARRY2: UR3.15 (TC), UR4.10 (CET)
/CEP: UR1.7 (CEP), UR2.7 (CEP), UR3.7 (CEP), UR4.7 (CEP)
/CLK: JP1.2 (B); also elsewhere on the board
/CLK_WB: UR1.2 (CP), UR2.2 (CP), UR3.2 (CP), UR4.2 (CP)
/D0: UNOT2.2, UOR1.4, UOR1.9
/D2: UNAND2.9, UNAND2.12, UNOT2.6
/D4: UNOT2.8
/D5: UNAND2.2, UNOT2.10
/D6: UNAND1.9, UNOT2.12
/DATAIN0: U2MUX3.4 (Za); also elsewhere on the board
/DATAIN1: U2MUX3.7 (Zb); also elsewhere on the board
/DATAIN2: U2MUX3.9 (Zc); also elsewhere on the board
/DATAIN3: U2MUX3.12 (Zd); also elsewhere on the board
/DATAIN4: U2MUX4.4 (Za); also elsewhere on the board
/DATAIN5: U2MUX4.7 (Zb); also elsewhere on the board
/DATAIN6: U2MUX4.9 (Zc); also elsewhere on the board
/DATAIN7: U2MUX4.12 (Zd); also elsewhere on the board
/DATAOUT_HIGH0: U2MUX2.3 (I1a); also elsewhere on the board
/DATAOUT_HIGH1: U2MUX2.6 (I1b); also elsewhere on the board
/DATAOUT_HIGH2: U2MUX2.10 (I1c); also elsewhere on the board
/DATAOUT_HIGH3: U2MUX2.13 (I1d); also elsewhere on the board
/DATAOUT_HIGH4: U2MUX1.3 (I1a); also elsewhere on the board
/DATAOUT_HIGH5: U2MUX1.6 (I1b); also elsewhere on the board
/DATAOUT_HIGH6: U2MUX1.10 (I1c); also elsewhere on the board
/DATAOUT_HIGH7: U2MUX1.13 (I1d); also elsewhere on the board
/DATAOUT_LOW0: U2MUX2.2 (I0a); also elsewhere on the board
/DATAOUT_LOW1: U2MUX2.5 (I0b); also elsewhere on the board
/DATAOUT_LOW2: U2MUX2.11 (I0c); also elsewhere on the board
/DATAOUT_LOW3: U2MUX2.14 (I0d); also elsewhere on the board
/DATAOUT_LOW4: U2MUX1.2 (I0a); also elsewhere on the board
/DATAOUT_LOW5: U2MUX1.5 (I0b); also elsewhere on the board
/DATAOUT_LOW6: U2MUX1.11 (I0c); also elsewhere on the board
/DATAOUT_LOW7: U2MUX1.14 (I0d); also elsewhere on the board
/FLAG_CARRY: UCONDMUX1.12 (I7)
/IMM0: UXOR1.1
/IMM1: UCONDMUX1.11 (S0)
/IMM2: UCONDMUX1.10 (S1)
/IMM3: UCONDMUX1.9 (S2)
/IN_IMMEDIATE3: U2MUX1.1 (S), U2MUX2.1 (S); also elsewhere on the board
/IN_R0: UNOT2.4; also elsewhere on the board
/IN_R2: UOR1.6; also elsewhere on the board
/IN_R3: UOR1.8; also elsewhere on the board
/IS_JUMP: UNAND1.13, UNOT1.2
/IS_SKIP: UNAND1.5, UNOT1.10
/MEM_DATA0: U2MUX3.2 (I0a); also elsewhere on the board
/MEM_DATA1: U2MUX3.5 (I0b); also elsewhere on the board
/MEM_DATA2: U2MUX3.11 (I0c); also elsewhere on the board
/MEM_DATA3: U2MUX3.14 (I0d); also elsewhere on the board
/MEM_DATA4: U2MUX4.2 (I0a); also elsewhere on the board
/MEM_DATA5: U2MUX4.5 (I0b); also elsewhere on the board
/MEM_DATA6: U2MUX4.11 (I0c); also elsewhere on the board
/MEM_DATA7: U2MUX4.14 (I0d); also elsewhere on the board
/NEWCOND: UCONDMUX1.3 (I1)
/OPCODE0: UNAND1.10, UNAND2.1, UNAND2.5, UNAND2.10, UNOT1.3; also elsewhere on the board
/OPCODE2: U5.2 (A1), UOR1.1, UOR1.5; also elsewhere on the board
/OPCODE3: U5.3 (A2), UOR1.2, UOR1.10; also elsewhere on the board
/OSC_IN: C27.2, R2.1, U1.2, Y1.2
/OSC_OUT: R2.2, R3.2, U1.4, UNOT1.9
/OUT_REGDATA0: U2MUX2.4 (Za); also elsewhere on the board
/OUT_REGDATA1: U2MUX2.7 (Zb); also elsewhere on the board
/OUT_REGDATA2: U2MUX2.9 (Zc); also elsewhere on the board
/OUT_REGDATA3: U2MUX2.12 (Zd); also elsewhere on the board
/OUT_REGDATA4: U2MUX1.4 (Za); also elsewhere on the board
/OUT_REGDATA5: U2MUX1.7 (Zb); also elsewhere on the board
/OUT_REGDATA6: U2MUX1.9 (Zc); also elsewhere on the board
/OUT_REGDATA7: U2MUX1.12 (Zd); also elsewhere on the board
/OVERFLOW: UR4.15 (TC)
/PCEVENT: UNAND1.4, UNAND1.12, UXOR1.3
/RCD0: UCMP1.3 (Q0); also elsewhere on the board
/RCD1: UCMP1.5 (Q1); also elsewhere on the board
/RCD2: UCMP1.7 (Q2); also elsewhere on the board
/RCD3: UCMP1.9 (Q3); also elsewhere on the board
/RCD4: UCMP1.12 (Q4); also elsewhere on the board
/RCD5: UCMP1.14 (Q5); also elsewhere on the board
/RCD6: UCMP1.16 (Q6); also elsewhere on the board
/RCD7: UCMP1.18 (Q7); also elsewhere on the board
/RCS1: UCMP1.4 (P1); also elsewhere on the board
/RCS2: UCMP1.6 (P2); also elsewhere on the board
/RCS3: UCMP1.8 (P3); also elsewhere on the board
/RCS4: UCMP1.11 (P4); also elsewhere on the board
/RCS5: UCMP1.13 (P5); also elsewhere on the board
/RCS6: UCMP1.15 (P6); also elsewhere on the board
/REGMEM0: UR1.3 (D0); also elsewhere on the board
/REGMEM1: UR1.4 (D1); also elsewhere on the board
/REGMEM2: UR1.5 (D2); also elsewhere on the board
/REGMEM3: UR1.6 (D3); also elsewhere on the board
/REGMEM4: UR2.3 (D0); also elsewhere on the board
/REGMEM5: UR2.4 (D1); also elsewhere on the board
/REGMEM6: UR2.5 (D2); also elsewhere on the board
/REGMEM7: UR2.6 (D3); also elsewhere on the board
/REGMEM8: UR3.3 (D0); also elsewhere on the board
/REGMEM9: UR3.4 (D1); also elsewhere on the board
/REGMEM10: UR3.5 (D2); also elsewhere on the board
/REGMEM11: UR3.6 (D3); also elsewhere on the board
/REGMEM12: UR4.3 (D0); also elsewhere on the board
/REGMEM13: UR4.4 (D1); also elsewhere on the board
/REGMEM14: UR4.5 (D2); also elsewhere on the board
/REGMEM15: UR4.6 (D3); also elsewhere on the board
/ROMADDR0: UR1.14 (Q0); also elsewhere on the board
/ROMADDR1: UR1.13 (Q1); also elsewhere on the board
/ROMADDR2: UR1.12 (Q2); also elsewhere on the board
/ROMADDR3: UR1.11 (Q3); also elsewhere on the board
/ROMADDR4: UR2.14 (Q0); also elsewhere on the board
/ROMADDR5: UR2.13 (Q1); also elsewhere on the board
/ROMADDR6: UR2.12 (Q2); also elsewhere on the board
/ROMADDR7: UR2.11 (Q3); also elsewhere on the board
/ROMADDR8: UR3.14 (Q0); also elsewhere on the board
/ROMADDR9: UR3.13 (Q1); also elsewhere on the board
/ROMADDR10: UR3.12 (Q2); also elsewhere on the board
/ROMADDR11: UR3.11 (Q3); also elsewhere on the board
/ROMADDR12: UR4.14 (Q0); also elsewhere on the board
/ROMADDR13: UR4.13 (Q1); also elsewhere on the board
/ROMADDR14: UR4.12 (Q2); also elsewhere on the board
/ROMADDR15: UR4.11 (Q3); also elsewhere on the board
/SWAP_NIBBLES: UNOT1.12; also elsewhere on the board
/~D0: U5.15 (~Y0), UNOT2.1
/~D1: U5.14 (~Y1), UNOT2.3
/~D2: U5.13 (~Y2), UNOT2.5, UXOR1.4
/~D4: U5.11 (~Y4), UNOT2.9
/~D5: U5.10 (~Y5), UNOT2.11
/~D6: U5.9 (~Y6), UNOT2.13
/~IS_JMP: UNAND1.11, UR1.9 (~PE), UR2.9 (~PE), UR3.9 (~PE), UR4.9 (~PE)
/~IS_SKIP: UNAND1.6
/~L: UNAND2.4, UOR1.3; also elsewhere on the board
/~MEMORY_READ: U2MUX3.1 (S), U2MUX4.1 (S), UNAND2.3
/~MEM_WE: UNAND1.8, UXOR1.5
/~OPCODE0: UNAND2.13, UNOT1.4
/~REG_WE: UXOR1.6; also elsewhere on the board
/~RST: SW1.1, UR1.1 (~MR), UR2.1 (~MR), UR3.1 (~MR), UR4.1 (~MR); also elsewhere on the board
GND: C1.2, C2.2, C3.2, C4.2, C5.2, C6.2, C7.2, C8.2, C9.2, C10.2, C11.2, C12.2, C13.2, C14.2, C15.2, C16.2, C17.2, C18.2, C19.2, C20.2, C21.2, C22.2, C23.2, C24.2, C25.2, C26.2, C27.1, C28.1, D1.2 (A), J1.2, SW1.2, U1.3 (GND), U2MUX1.8 (GND), U2MUX1.15 (E), U2MUX2.8 (GND), U2MUX2.15 (E), U2MUX3.8 (GND), U2MUX3.15 (E), U2MUX4.8 (GND), U2MUX4.15 (E), U5.4 (~G2A), U5.5 (~G2B), U5.8 (GND), UCMP1.10 (Gnd), UCONDMUX1.4 (I0), UCONDMUX1.7 (~E), UCONDMUX1.8 (GND), UNAND1.7 (GND), UNAND2.7 (GND), UNOT1.7 (GND), UNOT2.7 (GND), UOR1.7 (GND), UR1.8 (GND), UR2.8 (GND), UR3.8 (GND), UR4.8 (GND), UXOR1.7 (GND); also elsewhere on the board
unnamed: C28.2, R3.1, Y1.1
unnamed: JP1.1 (A), UNOT1.8
unnamed: UCONDMUX1.5 (Q), UXOR1.2
unnamed: UNAND2.6, UNOT1.13
unnamed: UNAND2.8, UNOT1.1
unnamed: UNAND2.11, UNOT1.11

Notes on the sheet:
CLOCK
POWER
Register Input Select
COUNTER
HC86 -> 20ns
<-- Roughly the Reactance?
Instruction Decode
TODO Replace with APX823-46W5G-7
55ns
Jumper for testing with function generator
14ns
HCS14 = 17ns
Propogation Delays (Not Counting Transition Times) HCS00 NAND 13ns HC08 AND 14ns HCS14 INV 17ns HCS32 OR 13ns HCS86 XOR 13ns HCS138 DEMUX 19ns HCS151 8:1MUX 14ns, any D HCS153 4:1MUX 17ns, ab input HCS157 2:1MUX 19ns, ab input AC283 ADD 36ns, 2-in-series HCS684 CMP 69ns
7ns
Motherboard Systems: - Opcode decoding - Reverse Bias Protection? - 5V zener diodes? - Check memory timing/WE?
Register Card Select
Conditional Logic
Pierce Oscillator
Decoupling Capacitors
TODO test on breadboard

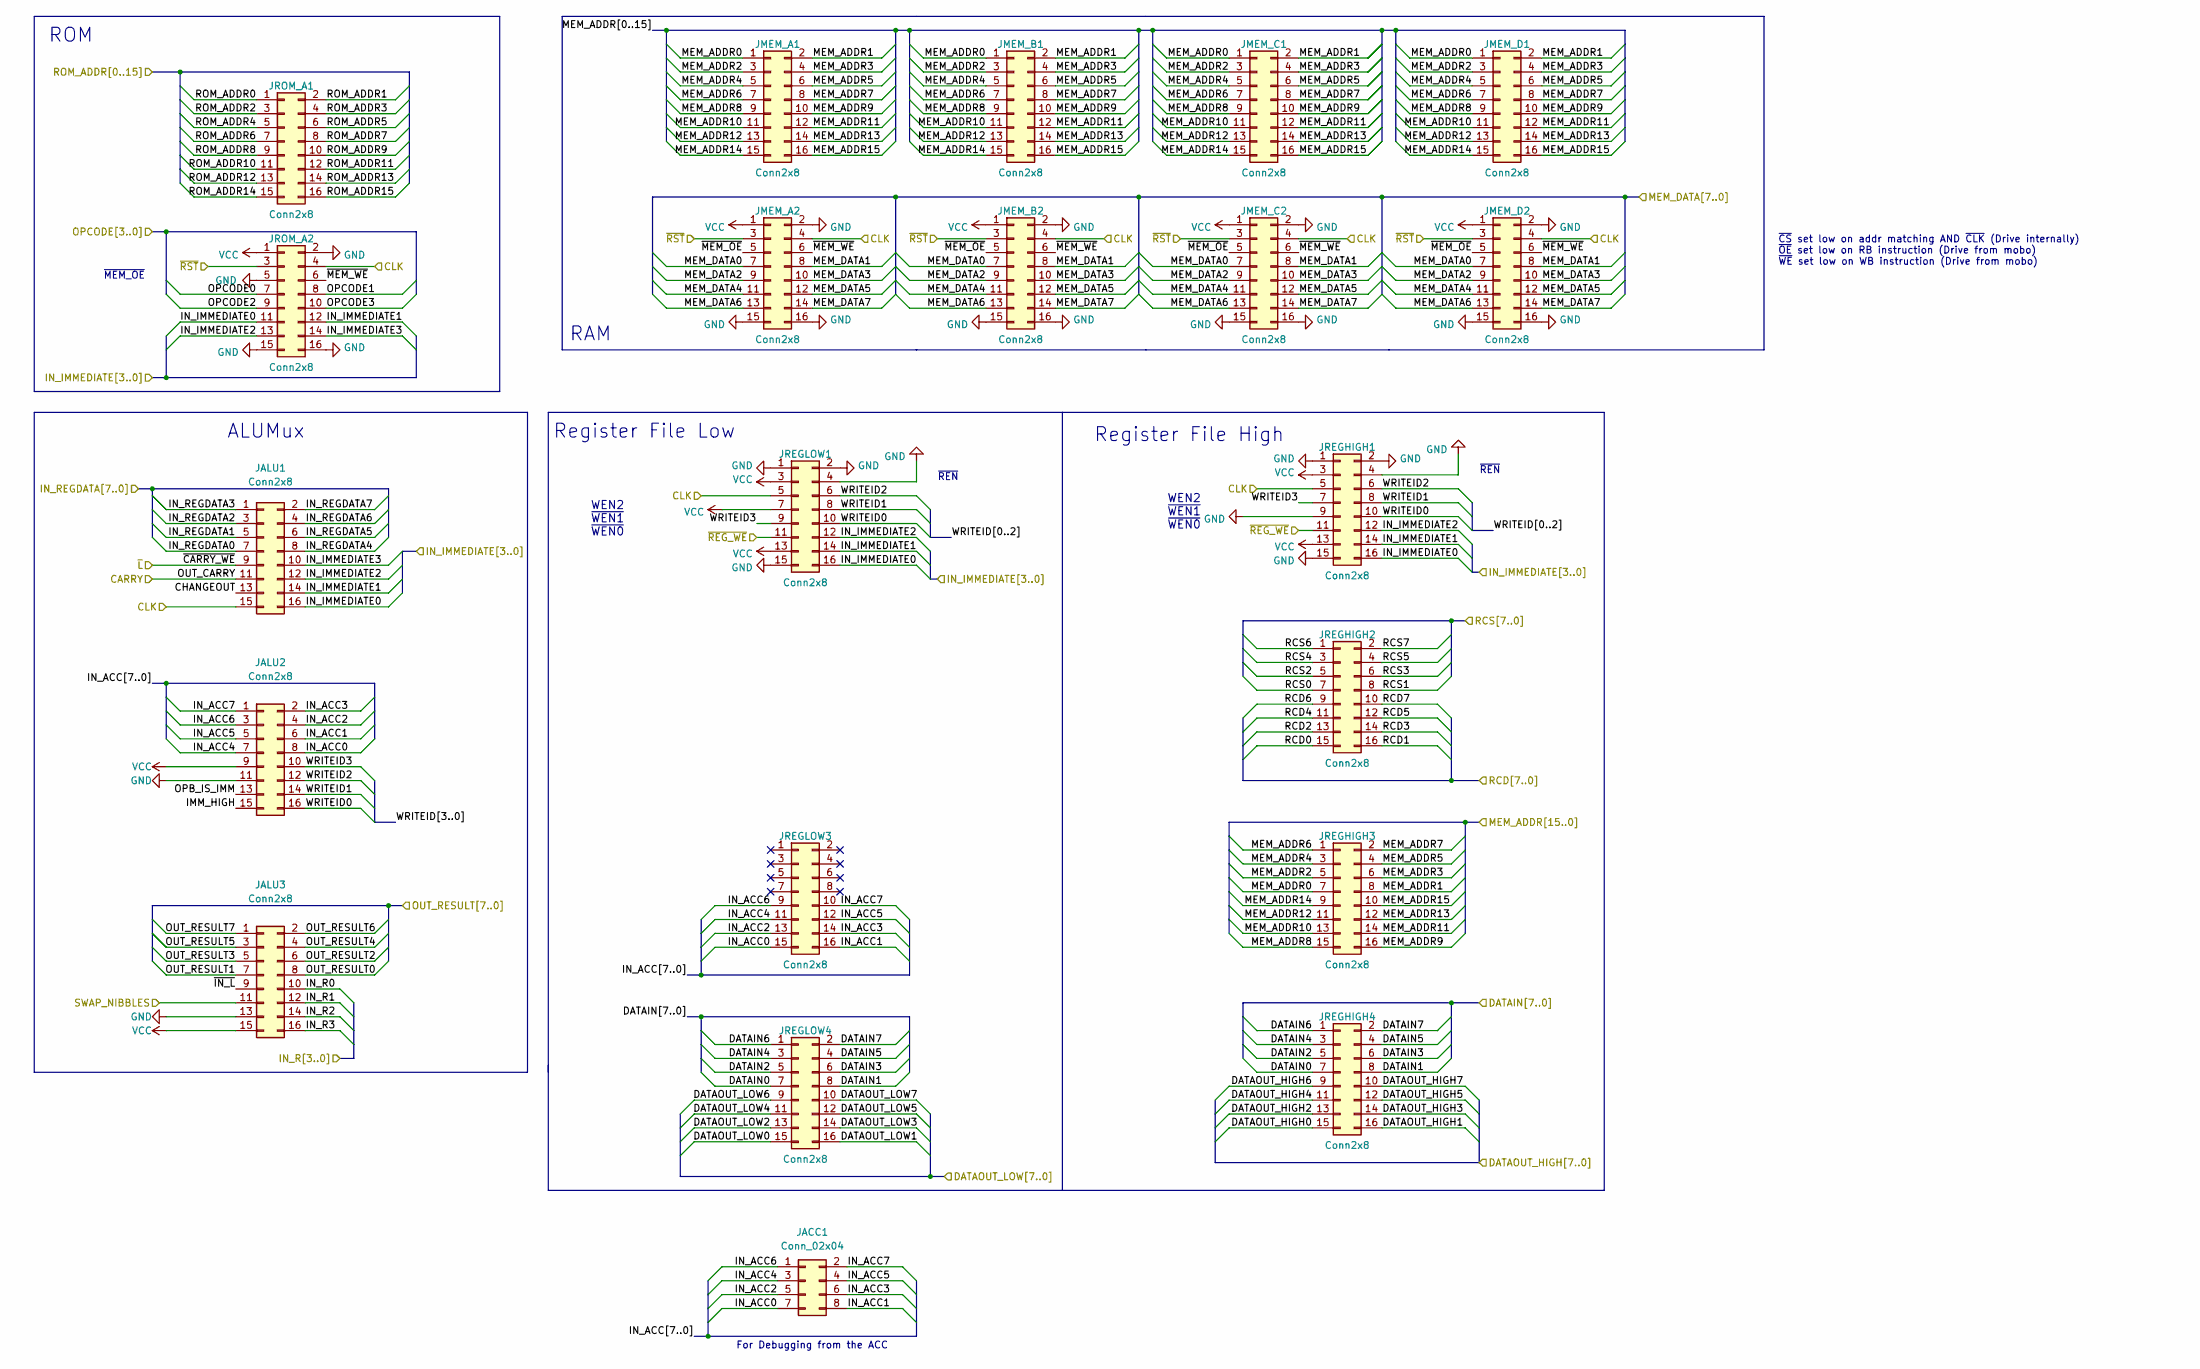
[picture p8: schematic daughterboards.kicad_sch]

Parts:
JACC1: Conn_02x04; PinHeader_2x04_P2.54mm_Vertical
JALU1, JALU2, JALU3: Conn2x8; PinSocket_2x08_P2.54mm_Vertical
JMEM_A1, JMEM_A2: Conn2x8; PinSocket_2x08_P2.54mm_Vertical
JMEM_B1, JMEM_B2: Conn2x8; PinSocket_2x08_P2.54mm_Vertical
JMEM_C1, JMEM_C2: Conn2x8; PinSocket_2x08_P2.54mm_Vertical
JMEM_D1, JMEM_D2: Conn2x8; PinSocket_2x08_P2.54mm_Vertical
JREGHIGH1, JREGHIGH2, JREGHIGH3, JREGHIGH4: Conn2x8; PinSocket_2x08_P2.54mm_Vertical
JREGLOW1, JREGLOW3, JREGLOW4: Conn2x8; PinSocket_2x08_P2.54mm_Vertical
JROM_A1, JROM_A2: Conn2x8; PinSocket_2x08_P2.54mm_Vertical

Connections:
/ALU_RESULT0: JALU3.8; also elsewhere on the board
/ALU_RESULT1: JALU3.7; also elsewhere on the board
/ALU_RESULT2: JALU3.6; also elsewhere on the board
/ALU_RESULT3: JALU3.5; also elsewhere on the board
/ALU_RESULT4: JALU3.4; also elsewhere on the board
/ALU_RESULT5: JALU3.3; also elsewhere on the board
/ALU_RESULT6: JALU3.2; also elsewhere on the board
/ALU_RESULT7: JALU3.1; also elsewhere on the board
/CLK: JALU1.15, JMEM_A2.4, JMEM_B2.4, JMEM_C2.4, JMEM_D2.4, JREGHIGH1.5, JREGLOW1.5, JROM_A2.4; also elsewhere on the board
/DATAIN0: JREGHIGH4.7, JREGLOW4.7; also elsewhere on the board
/DATAIN1: JREGHIGH4.8, JREGLOW4.8; also elsewhere on the board
/DATAIN2: JREGHIGH4.5, JREGLOW4.5; also elsewhere on the board
/DATAIN3: JREGHIGH4.6, JREGLOW4.6; also elsewhere on the board
/DATAIN4: JREGHIGH4.3, JREGLOW4.3; also elsewhere on the board
/DATAIN5: JREGHIGH4.4, JREGLOW4.4; also elsewhere on the board
/DATAIN6: JREGHIGH4.1, JREGLOW4.1; also elsewhere on the board
/DATAIN7: JREGHIGH4.2, JREGLOW4.2; also elsewhere on the board
/DATAOUT_HIGH0: JREGHIGH4.15; also elsewhere on the board
/DATAOUT_HIGH1: JREGHIGH4.16; also elsewhere on the board
/DATAOUT_HIGH2: JREGHIGH4.13; also elsewhere on the board
/DATAOUT_HIGH3: JREGHIGH4.14; also elsewhere on the board
/DATAOUT_HIGH4: JREGHIGH4.11; also elsewhere on the board
/DATAOUT_HIGH5: JREGHIGH4.12; also elsewhere on the board
/DATAOUT_HIGH6: JREGHIGH4.9; also elsewhere on the board
/DATAOUT_HIGH7: JREGHIGH4.10; also elsewhere on the board
/DATAOUT_LOW0: JREGLOW4.15; also elsewhere on the board
/DATAOUT_LOW1: JREGLOW4.16; also elsewhere on the board
/DATAOUT_LOW2: JREGLOW4.13; also elsewhere on the board
/DATAOUT_LOW3: JREGLOW4.14; also elsewhere on the board
/DATAOUT_LOW4: JREGLOW4.11; also elsewhere on the board
/DATAOUT_LOW5: JREGLOW4.12; also elsewhere on the board
/DATAOUT_LOW6: JREGLOW4.9; also elsewhere on the board
/DATAOUT_LOW7: JREGLOW4.10; also elsewhere on the board
/Daughter Boards/CHANGEOUT: JALU1.13
/Daughter Boards/IMM_HIGH: JALU2.15
/Daughter Boards/IN_ACC0: JACC1.7, JALU2.8, JREGLOW3.15
/Daughter Boards/IN_ACC1: JACC1.8, JALU2.6, JREGLOW3.16
/Daughter Boards/IN_ACC2: JACC1.5, JALU2.4, JREGLOW3.13
/Daughter Boards/IN_ACC3: JACC1.6, JALU2.2, JREGLOW3.14
/Daughter Boards/IN_ACC4: JACC1.3, JALU2.7, JREGLOW3.11
/Daughter Boards/IN_ACC5: JACC1.4, JALU2.5, JREGLOW3.12
/Daughter Boards/IN_ACC6: JACC1.1, JALU2.3, JREGLOW3.9
/Daughter Boards/IN_ACC7: JACC1.2, JALU2.1, JREGLOW3.10
/Daughter Boards/OPB_IS_IMM: JALU2.13
/Daughter Boards/OUT_CARRY: JALU1.11
/Daughter Boards/WRITEID0: JALU2.16, JREGHIGH1.10, JREGLOW1.10
/Daughter Boards/WRITEID1: JALU2.14, JREGHIGH1.8, JREGLOW1.8
/Daughter Boards/WRITEID2: JALU2.12, JREGHIGH1.6, JREGLOW1.6
/Daughter Boards/WRITEID3: JALU2.10, JREGHIGH1.7, JREGLOW1.9
/Daughter Boards/~IN_L: JALU3.9
/Daughter Boards/~MEM_OE: JMEM_A2.5, JMEM_B2.5, JMEM_C2.5, JMEM_D2.5
/Daughter Boards/~MEM_WE: JMEM_A2.6, JMEM_B2.6, JMEM_C2.6, JMEM_D2.6, JROM_A2.6
/IN_IMMEDIATE0: JALU1.16, JREGHIGH1.16, JREGLOW1.16, JROM_A2.11
/IN_IMMEDIATE1: JALU1.14, JREGHIGH1.14, JREGLOW1.14, JROM_A2.12
/IN_IMMEDIATE2: JALU1.12, JREGHIGH1.12, JREGLOW1.12, JROM_A2.13
/IN_IMMEDIATE3: JALU1.10, JROM_A2.14; also elsewhere on the board
/IN_R0: JALU3.10; also elsewhere on the board
/IN_R1: JALU3.12, JROM_A2.8
/IN_R2: JALU3.14; also elsewhere on the board
/IN_R3: JALU3.16; also elsewhere on the board
/MEM_DATA0: JMEM_A2.7, JMEM_B2.7, JMEM_C2.7, JMEM_D2.7; also elsewhere on the board
/MEM_DATA1: JMEM_A2.8, JMEM_B2.8, JMEM_C2.8, JMEM_D2.8; also elsewhere on the board
/MEM_DATA2: JMEM_A2.9, JMEM_B2.9, JMEM_C2.9, JMEM_D2.9; also elsewhere on the board
/MEM_DATA3: JMEM_A2.10, JMEM_B2.10, JMEM_C2.10, JMEM_D2.10; also elsewhere on the board
/MEM_DATA4: JMEM_A2.11, JMEM_B2.11, JMEM_C2.11, JMEM_D2.11; also elsewhere on the board
/MEM_DATA5: JMEM_A2.12, JMEM_B2.12, JMEM_C2.12, JMEM_D2.12; also elsewhere on the board
/MEM_DATA6: JMEM_A2.13, JMEM_B2.13, JMEM_C2.13, JMEM_D2.13; also elsewhere on the board
/MEM_DATA7: JMEM_A2.14, JMEM_B2.14, JMEM_C2.14, JMEM_D2.14; also elsewhere on the board
/OPCODE0: JROM_A2.7; also elsewhere on the board
/OPCODE2: JROM_A2.9; also elsewhere on the board
/OPCODE3: JROM_A2.10; also elsewhere on the board
/OUT_REGDATA0: JALU1.7; also elsewhere on the board
/OUT_REGDATA1: JALU1.5; also elsewhere on the board
/OUT_REGDATA2: JALU1.3; also elsewhere on the board
/OUT_REGDATA3: JALU1.1; also elsewhere on the board
/OUT_REGDATA4: JALU1.8; also elsewhere on the board
/OUT_REGDATA5: JALU1.6; also elsewhere on the board
/OUT_REGDATA6: JALU1.4; also elsewhere on the board
/OUT_REGDATA7: JALU1.2; also elsewhere on the board
/RCD0: JREGHIGH2.15; also elsewhere on the board
/RCD1: JREGHIGH2.16; also elsewhere on the board
/RCD2: JREGHIGH2.13; also elsewhere on the board
/RCD3: JREGHIGH2.14; also elsewhere on the board
/RCD4: JREGHIGH2.11; also elsewhere on the board
/RCD5: JREGHIGH2.12; also elsewhere on the board
/RCD6: JREGHIGH2.9; also elsewhere on the board
/RCD7: JREGHIGH2.10; also elsewhere on the board
/RCS1: JREGHIGH2.8; also elsewhere on the board
/RCS2: JREGHIGH2.5; also elsewhere on the board
/RCS3: JREGHIGH2.6; also elsewhere on the board
/RCS4: JREGHIGH2.3; also elsewhere on the board
/RCS5: JREGHIGH2.4; also elsewhere on the board
/RCS6: JREGHIGH2.1; also elsewhere on the board
/REGMEM0: JMEM_A1.1, JMEM_B1.1, JMEM_C1.1, JMEM_D1.1, JREGHIGH3.7; also elsewhere on the board
/REGMEM1: JMEM_A1.2, JMEM_B1.2, JMEM_C1.2, JMEM_D1.2, JREGHIGH3.8; also elsewhere on the board
/REGMEM2: JMEM_A1.3, JMEM_B1.3, JMEM_C1.3, JMEM_D1.3, JREGHIGH3.5; also elsewhere on the board
/REGMEM3: JMEM_A1.4, JMEM_B1.4, JMEM_C1.4, JMEM_D1.4, JREGHIGH3.6; also elsewhere on the board
/REGMEM4: JMEM_A1.5, JMEM_B1.5, JMEM_C1.5, JMEM_D1.5, JREGHIGH3.3; also elsewhere on the board
/REGMEM5: JMEM_A1.6, JMEM_B1.6, JMEM_C1.6, JMEM_D1.6, JREGHIGH3.4; also elsewhere on the board
/REGMEM6: JMEM_A1.7, JMEM_B1.7, JMEM_C1.7, JMEM_D1.7, JREGHIGH3.1; also elsewhere on the board
/REGMEM7: JMEM_A1.8, JMEM_B1.8, JMEM_C1.8, JMEM_D1.8, JREGHIGH3.2; also elsewhere on the board
/REGMEM8: JMEM_A1.9, JMEM_B1.9, JMEM_C1.9, JMEM_D1.9, JREGHIGH3.15; also elsewhere on the board
/REGMEM9: JMEM_A1.10, JMEM_B1.10, JMEM_C1.10, JMEM_D1.10, JREGHIGH3.16; also elsewhere on the board
/REGMEM10: JMEM_A1.11, JMEM_B1.11, JMEM_C1.11, JMEM_D1.11, JREGHIGH3.13; also elsewhere on the board
/REGMEM11: JMEM_A1.12, JMEM_B1.12, JMEM_C1.12, JMEM_D1.12, JREGHIGH3.14; also elsewhere on the board
/REGMEM12: JMEM_A1.13, JMEM_B1.13, JMEM_C1.13, JMEM_D1.13, JREGHIGH3.11; also elsewhere on the board
/REGMEM13: JMEM_A1.14, JMEM_B1.14, JMEM_C1.14, JMEM_D1.14, JREGHIGH3.12; also elsewhere on the board
/REGMEM14: JMEM_A1.15, JMEM_B1.15, JMEM_C1.15, JMEM_D1.15, JREGHIGH3.9; also elsewhere on the board
/REGMEM15: JMEM_A1.16, JMEM_B1.16, JMEM_C1.16, JMEM_D1.16, JREGHIGH3.10; also elsewhere on the board
/ROMADDR0: JROM_A1.1; also elsewhere on the board
/ROMADDR1: JROM_A1.2; also elsewhere on the board
/ROMADDR2: JROM_A1.3; also elsewhere on the board
/ROMADDR3: JROM_A1.4; also elsewhere on the board
/ROMADDR4: JROM_A1.5; also elsewhere on the board
/ROMADDR5: JROM_A1.6; also elsewhere on the board
/ROMADDR6: JROM_A1.7; also elsewhere on the board
/ROMADDR7: JROM_A1.8; also elsewhere on the board
/ROMADDR8: JROM_A1.9; also elsewhere on the board
/ROMADDR9: JROM_A1.10; also elsewhere on the board
/ROMADDR10: JROM_A1.11; also elsewhere on the board
/ROMADDR11: JROM_A1.12; also elsewhere on the board
/ROMADDR12: JROM_A1.13; also elsewhere on the board
/ROMADDR13: JROM_A1.14; also elsewhere on the board
/ROMADDR14: JROM_A1.15; also elsewhere on the board
/ROMADDR15: JROM_A1.16; also elsewhere on the board
/SWAP_NIBBLES: JALU3.11; also elsewhere on the board
/~L: JALU1.9; also elsewhere on the board
/~REG_WE: JREGHIGH1.11, JREGLOW1.11; also elsewhere on the board
/~RST: JMEM_A2.3, JMEM_B2.3, JMEM_C2.3, JMEM_D2.3, JROM_A2.3; also elsewhere on the board
GND: JALU2.11, JALU3.13, JMEM_A2.2, JMEM_A2.15, JMEM_A2.16, JMEM_B2.2, JMEM_B2.15, JMEM_B2.16, JMEM_C2.2, JMEM_C2.15, JMEM_C2.16, JMEM_D2.2, JMEM_D2.15, JMEM_D2.16, JREGHIGH1.1, JREGHIGH1.2, JREGHIGH1.4, JREGHIGH1.9, JREGHIGH1.15, JREGLOW1.1, JREGLOW1.2, JREGLOW1.4, JREGLOW1.15, JROM_A2.2, JROM_A2.5, JROM_A2.15, JROM_A2.16; also elsewhere on the board

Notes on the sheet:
WEN2 ~{WEN1} ~{WEN0}
For Debugging from the ACC
~{REN}
Register File High
ALUMux
RAM
ROM
Register File Low
~{MEM_OE}
~{CS} set low on addr matching AND ~{CLK} (Drive internally) ~{OE} set low on RB instruction (Drive from mobo) ~{WE} set low on WB instruction (Drive from mobo)

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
Board: 4 copper layers, 73 parts (29 on the bottom side), 157 nets, no tracks yet.

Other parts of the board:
R1: 10k; R_1206_3216Metric_Pad1.30x1.75mm_HandSolder

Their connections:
/~RST: R1.2; also elsewhere on the board

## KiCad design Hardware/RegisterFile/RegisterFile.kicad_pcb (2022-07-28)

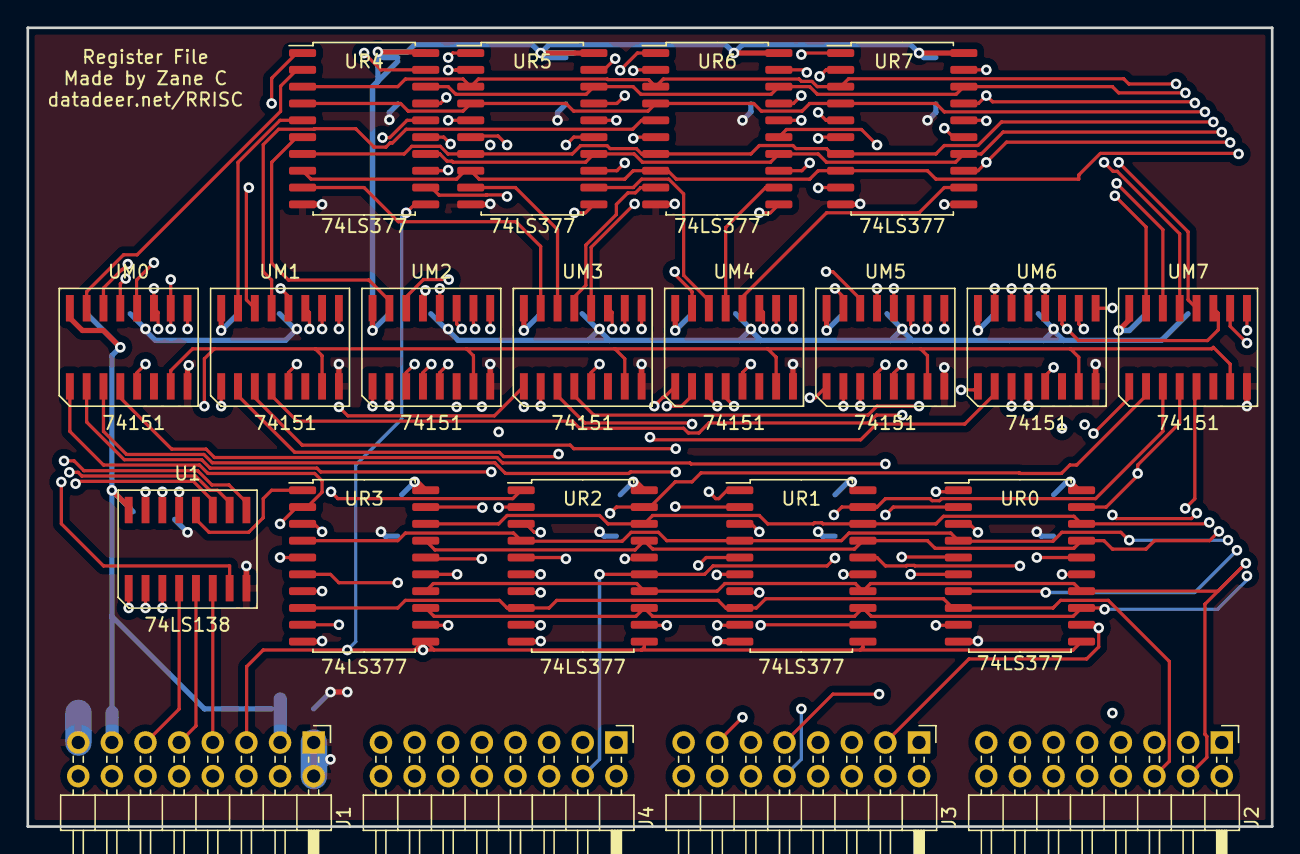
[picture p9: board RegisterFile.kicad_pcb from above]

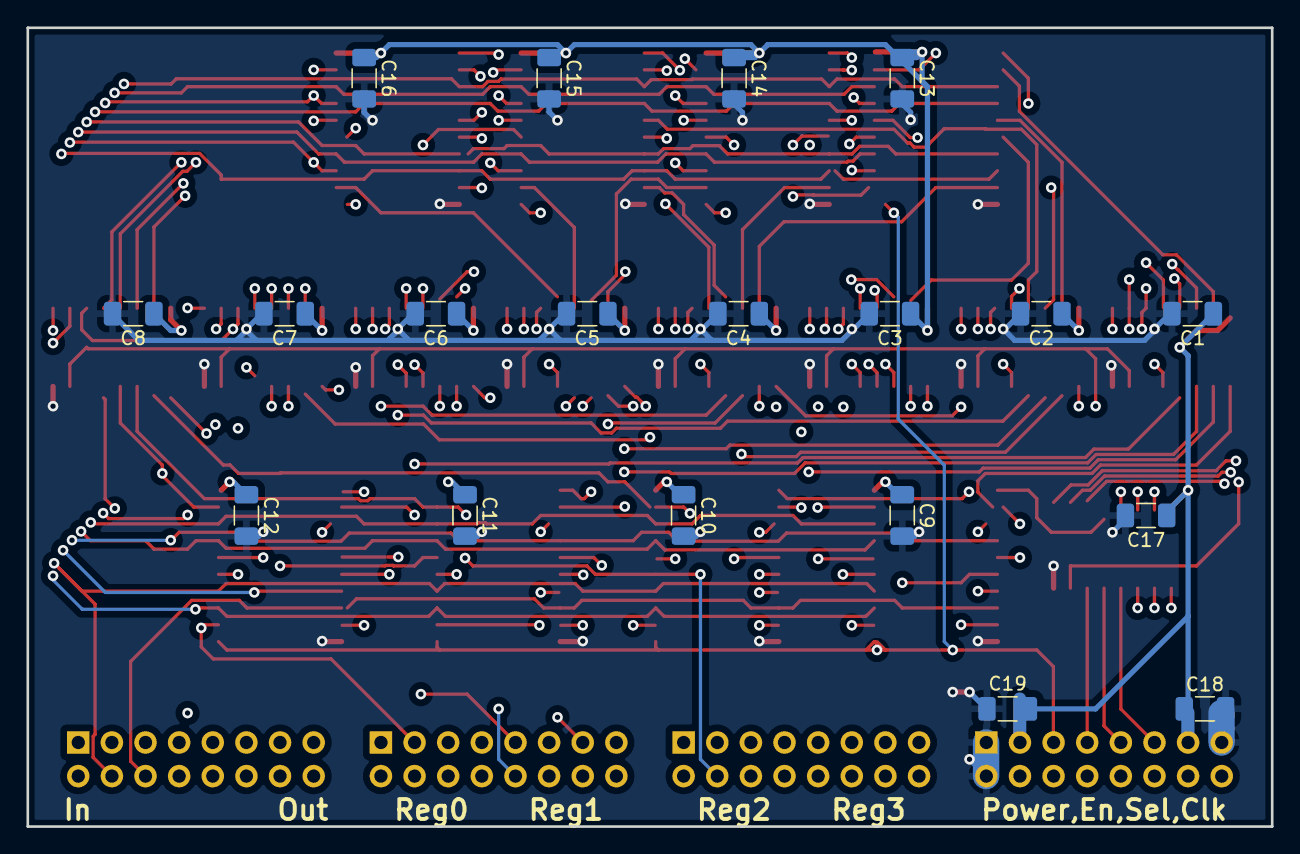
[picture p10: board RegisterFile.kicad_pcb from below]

Board: 4 copper layers, 94.0 x 60.3 mm, 40 parts (19 on the bottom side), 101 nets.

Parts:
C1, C2, C3, C4, C5, C6, C7, C8, C9, C10, C11, C12, C13, C14, C15, C16, C17, C18, C19: .1uF; C_1206_3216Metric_Pad1.33x1.80mm_HandSolder
J1, J2, J3, J4: Conn_02x08_Odd_Even; PinHeader_2x08_P2.54mm_Horizontal
U1: 74LS138; R-PDSO-G16
UM0, UM1, UM2, UM3, UM4, UM5, UM6, UM7: 74151; R-PDSO-G16
UR0, UR1, UR2, UR3, UR4, UR5, UR6, UR7: 74LS377; SOIC-20W_7.5x12.8mm_P1.27mm

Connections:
/CLK: J1.5, UR0.11 (CP), UR1.11 (CP), UR2.11 (CP), UR3.11 (CP), UR4.11 (CP), UR5.11 (CP), UR6.11 (CP), UR7.11 (CP)
/DATAIN0: J2.7, UR0.3 (D0), UR1.3 (D0), UR2.3 (D0), UR3.3 (D0), UR4.3 (D0), UR5.3 (D0), UR6.3 (D0), UR7.3 (D0)
/DATAIN1: J2.8, UR0.4 (D1), UR1.4 (D1), UR2.4 (D1), UR3.4 (D1), UR4.4 (D1), UR5.4 (D1), UR6.4 (D1), UR7.4 (D1)
/DATAIN2: J2.5, UR0.7 (D2), UR1.7 (D2), UR2.7 (D2), UR3.7 (D2), UR4.7 (D2), UR5.7 (D2), UR6.7 (D2), UR7.7 (D2)
/DATAIN3: J2.6, UR0.8 (D3), UR1.8 (D3), UR2.8 (D3), UR3.8 (D3), UR4.8 (D3), UR5.8 (D3), UR6.8 (D3), UR7.8 (D3)
/DATAIN4: J2.3, UR0.13 (D4), UR1.13 (D4), UR2.13 (D4), UR3.13 (D4), UR4.13 (D4), UR5.13 (D4), UR6.13 (D4), UR7.13 (D4)
/DATAIN5: J2.4, UR0.14 (D5), UR1.14 (D5), UR2.14 (D5), UR3.14 (D5), UR4.14 (D5), UR5.14 (D5), UR6.14 (D5), UR7.14 (D5)
/DATAIN6: J2.1, UR0.17 (D6), UR1.17 (D6), UR2.17 (D6), UR3.17 (D6), UR4.17 (D6), UR5.17 (D6), UR6.17 (D6), UR7.17 (D6)
/DATAIN7: J2.2, UR0.18 (D7), UR1.18 (D7), UR2.18 (D7), UR3.18 (D7), UR4.18 (D7), UR5.18 (D7), UR6.18 (D7), UR7.18 (D7)
/DATAOUT0: J2.15, UM0.5 (Q)
/DATAOUT1: J2.16, UM1.5 (Q)
/DATAOUT2: J2.13, UM2.5 (Q)
/DATAOUT3: J2.14, UM3.5 (Q)
/DATAOUT4: J2.11, UM4.5 (Q)
/DATAOUT5: J2.12, UM5.5 (Q)
/DATAOUT6: J2.9, UM6.5 (Q)
/DATAOUT7: J2.10, UM7.5 (Q)
/READID0: J1.16, UM0.11 (S0), UM1.11 (S0), UM2.11 (S0), UM3.11 (S0), UM4.11 (S0), UM5.11 (S0), UM6.11 (S0), UM7.11 (S0)
/READID1: J1.14, UM0.10 (S1), UM1.10 (S1), UM2.10 (S1), UM3.10 (S1), UM4.10 (S1), UM5.10 (S1), UM6.10 (S1), UM7.10 (S1)
/READID2: J1.12, UM0.9 (S2), UM1.9 (S2), UM2.9 (S2), UM3.9 (S2), UM4.9 (S2), UM5.9 (S2), UM6.9 (S2), UM7.9 (S2)
/REG0_0: J3.7, UM0.4 (I0), UR0.2 (Q0)
/REG0_1: J3.8, UM1.4 (I0), UR0.5 (Q1)
/REG0_2: J3.5, UM2.4 (I0), UR0.6 (Q2)
/REG0_3: J3.6, UM3.4 (I0), UR0.9 (Q3)
/REG0_4: J3.3, UM4.4 (I0), UR0.12 (Q4)
/REG0_5: J3.4, UM5.4 (I0), UR0.15 (Q5)
/REG0_6: J3.1, UM6.4 (I0), UR0.16 (Q6)
/REG0_7: J3.2, UM7.4 (I0), UR0.19 (Q7)
/REG1_0: J3.15, UM0.3 (I1), UR1.2 (Q0)
/REG1_1: J3.16, UM1.3 (I1), UR1.5 (Q1)
/REG1_2: J3.13, UM2.3 (I1), UR1.6 (Q2)
/REG1_3: J3.14, UM3.3 (I1), UR1.9 (Q3)
/REG1_4: J3.11, UM4.3 (I1), UR1.12 (Q4)
/REG1_5: J3.12, UM5.3 (I1), UR1.15 (Q5)
/REG1_6: J3.9, UM6.3 (I1), UR1.16 (Q6)
/REG1_7: J3.10, UM7.3 (I1), UR1.19 (Q7)
/REG2_0: J4.7, UM0.2 (I2), UR2.2 (Q0)
/REG2_1: J4.8, UM1.2 (I2), UR2.5 (Q1)
/REG2_2: J4.5, UM2.2 (I2), UR2.6 (Q2)
/REG2_3: J4.6, UM3.2 (I2), UR2.9 (Q3)
/REG2_4: J4.3, UM4.2 (I2), UR2.12 (Q4)
/REG2_5: J4.4, UM5.2 (I2), UR2.15 (Q5)
/REG2_6: J4.1, UM6.2 (I2), UR2.16 (Q6)
/REG2_7: J4.2, UM7.2 (I2), UR2.19 (Q7)
/REG3_0: J4.15, UM0.1 (I3), UR3.2 (Q0)
/REG3_1: J4.16, UM1.1 (I3), UR3.5 (Q1)
/REG3_2: J4.13, UM2.1 (I3), UR3.6 (Q2)
/REG3_3: J4.14, UM3.1 (I3), UR3.9 (Q3)
/REG3_4: J4.11, UM4.1 (I3), UR3.12 (Q4)
/REG3_5: J4.12, UM5.1 (I3), UR3.15 (Q5)
/REG3_6: J4.9, UM6.1 (I3), UR3.16 (Q6)
/REG3_7: J4.10, UM7.1 (I3), UR3.19 (Q7)
/REG4_0: UM0.15 (I4), UR4.2 (Q0)
/REG4_1: UM1.15 (I4), UR4.5 (Q1)
/REG4_2: UM2.15 (I4), UR4.6 (Q2)
/REG4_3: UM3.15 (I4), UR4.9 (Q3)
/REG4_4: UM4.15 (I4), UR4.12 (Q4)
/REG4_5: UM5.15 (I4), UR4.15 (Q5)
/REG4_6: UM6.15 (I4), UR4.16 (Q6)
/REG4_7: UM7.15 (I4), UR4.19 (Q7)
/REG5_0: UM0.14 (I5), UR5.2 (Q0)
/REG5_1: UM1.14 (I5), UR5.5 (Q1)
/REG5_2: UM2.14 (I5), UR5.6 (Q2)
/REG5_3: UM3.14 (I5), UR5.9 (Q3)
/REG5_4: UM4.14 (I5), UR5.12 (Q4)
/REG5_5: UM5.14 (I5), UR5.15 (Q5)
/REG5_6: UM6.14 (I5), UR5.16 (Q6)
/REG5_7: UM7.14 (I5), UR5.19 (Q7)
/REG6_0: UM0.13 (I6), UR6.2 (Q0)
/REG6_1: UM1.13 (I6), UR6.5 (Q1)
/REG6_2: UM2.13 (I6), UR6.6 (Q2)
/REG6_3: UM3.13 (I6), UR6.9 (Q3)
/REG6_4: UM4.13 (I6), UR6.12 (Q4)
/REG6_5: UM5.13 (I6), UR6.15 (Q5)
/REG6_6: UM6.13 (I6), UR6.16 (Q6)
/REG6_7: UM7.13 (I6), UR6.19 (Q7)
/REG7_0: UM0.12 (I7), UR7.2 (Q0)
/REG7_1: UM1.12 (I7), UR7.5 (Q1)
/REG7_2: UM2.12 (I7), UR7.6 (Q2)
/REG7_3: UM3.12 (I7), UR7.9 (Q3)
/REG7_4: UM4.12 (I7), UR7.12 (Q4)
/REG7_5: UM5.12 (I7), UR7.15 (Q5)
/REG7_6: UM6.12 (I7), UR7.16 (Q6)
/REG7_7: UM7.12 (I7), UR7.19 (Q7)
/Regs/~WRITESEL0: U1.15 (~Y0), UR0.1 (~E)
/Regs/~WRITESEL1: U1.14 (~Y1), UR1.1 (~E)
/Regs/~WRITESEL2: U1.13 (~Y2), UR2.1 (~E)
/Regs/~WRITESEL3: U1.12 (~Y3), UR3.1 (~E)
/Regs/~WRITESEL4: U1.11 (~Y4), UR4.1 (~E)
/Regs/~WRITESEL5: U1.10 (~Y5), UR5.1 (~E)
/Regs/~WRITESEL6: U1.9 (~Y6), UR6.1 (~E)
/Regs/~WRITESEL7: U1.7 (~Y7), UR7.1 (~E)
/WEN2: J1.7, U1.6 (G1)
/WRITEID0: J1.10, U1.1 (A0)
/WRITEID1: J1.8, U1.2 (A1)
/WRITEID2: J1.6, U1.3 (A2)
/~REN: J1.4, UM0.7 (~E), UM1.7 (~E), UM2.7 (~E), UM3.7 (~E), UM4.7 (~E), UM5.7 (~E), UM6.7 (~E), UM7.7 (~E)
/~WEN0: J1.11, U1.4 (~G2A)
/~WEN1: J1.9, U1.5 (~G2B)
GND: C1.2, C2.2, C3.2, C4.2, C5.2, C6.2, C7.2, C8.2, C9.2, C10.2, C11.2, C12.2, C13.2, C14.2, C15.2, C16.2, C17.2, C18.2, C19.2, J1.1, J1.2, J1.15, U1.8 (GND), UM0.8 (GND), UM1.8 (GND), UM2.8 (GND), UM3.8 (GND), UM4.8 (GND), UM5.8 (GND), UM6.8 (GND), UM7.8 (GND), UR0.10 (GND), UR1.10 (GND), UR2.10 (GND), UR3.10 (GND), UR4.10 (GND), UR5.10 (GND), UR6.10 (GND), UR7.10 (GND)
VCC: C1.1, C2.1, C3.1, C4.1, C5.1, C6.1, C7.1, C8.1, C9.1, C10.1, C11.1, C12.1, C13.1, C14.1, C15.1, C16.1, C17.1, C18.1, C19.1, J1.3, J1.13, U1.16 (VCC), UM0.16 (VCC), UM1.16 (VCC), UM2.16 (VCC), UM3.16 (VCC), UM4.16 (VCC), UM5.16 (VCC), UM6.16 (VCC), UM7.16 (VCC), UR0.20 (VCC), UR1.20 (VCC), UR2.20 (VCC), UR3.20 (VCC), UR4.20 (VCC), UR5.20 (VCC), UR6.20 (VCC), UR7.20 (VCC)

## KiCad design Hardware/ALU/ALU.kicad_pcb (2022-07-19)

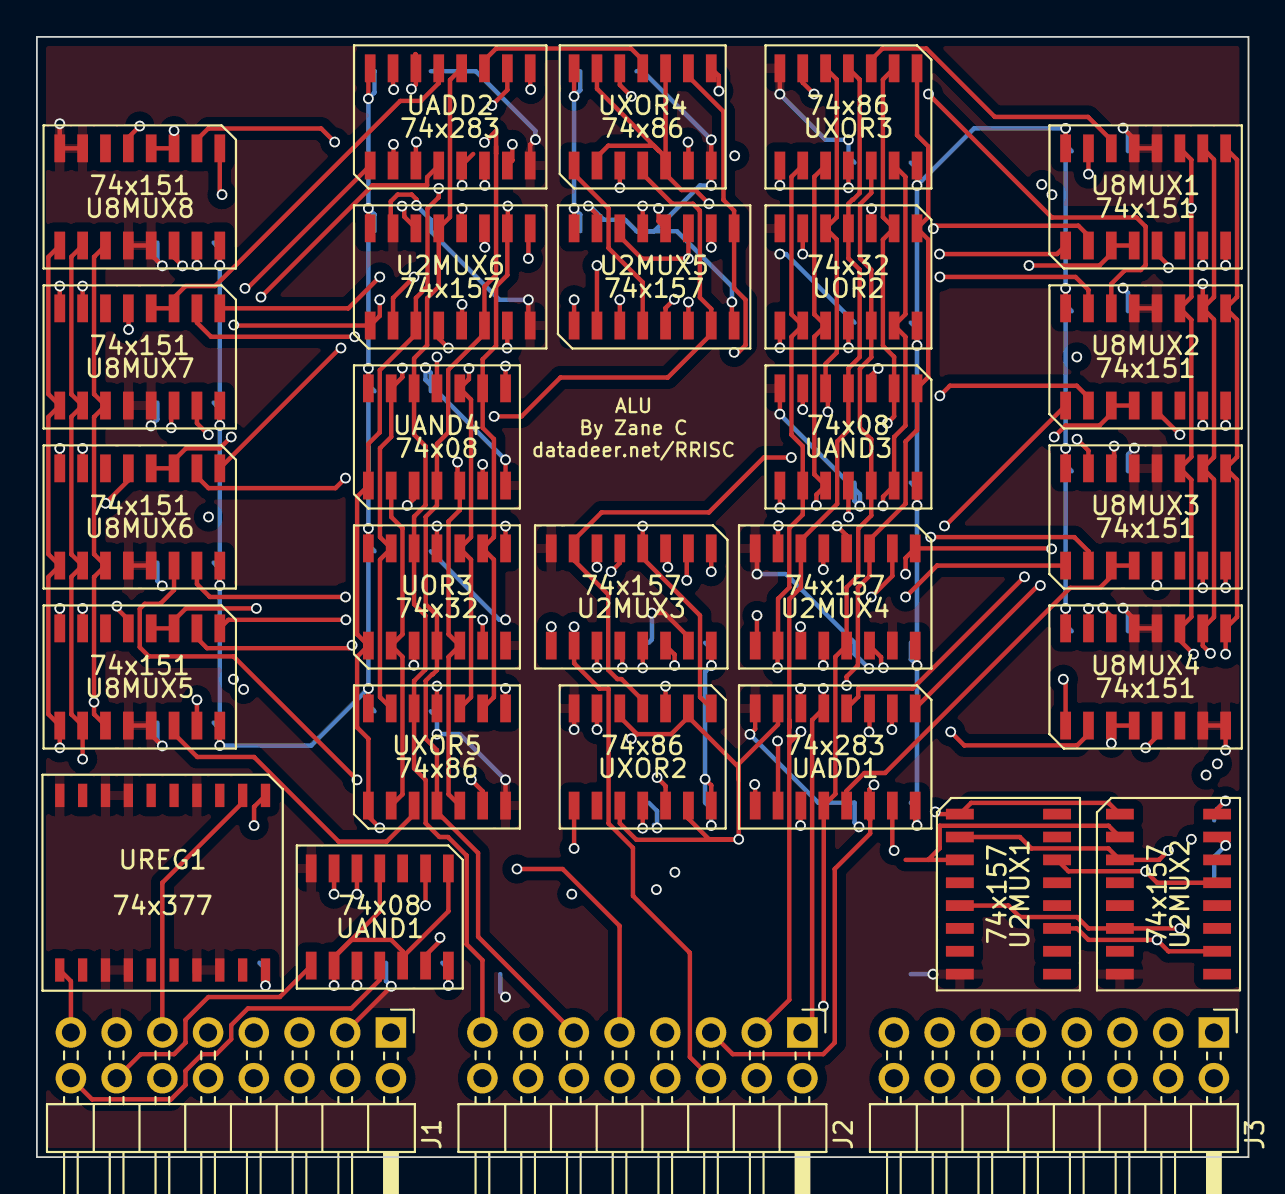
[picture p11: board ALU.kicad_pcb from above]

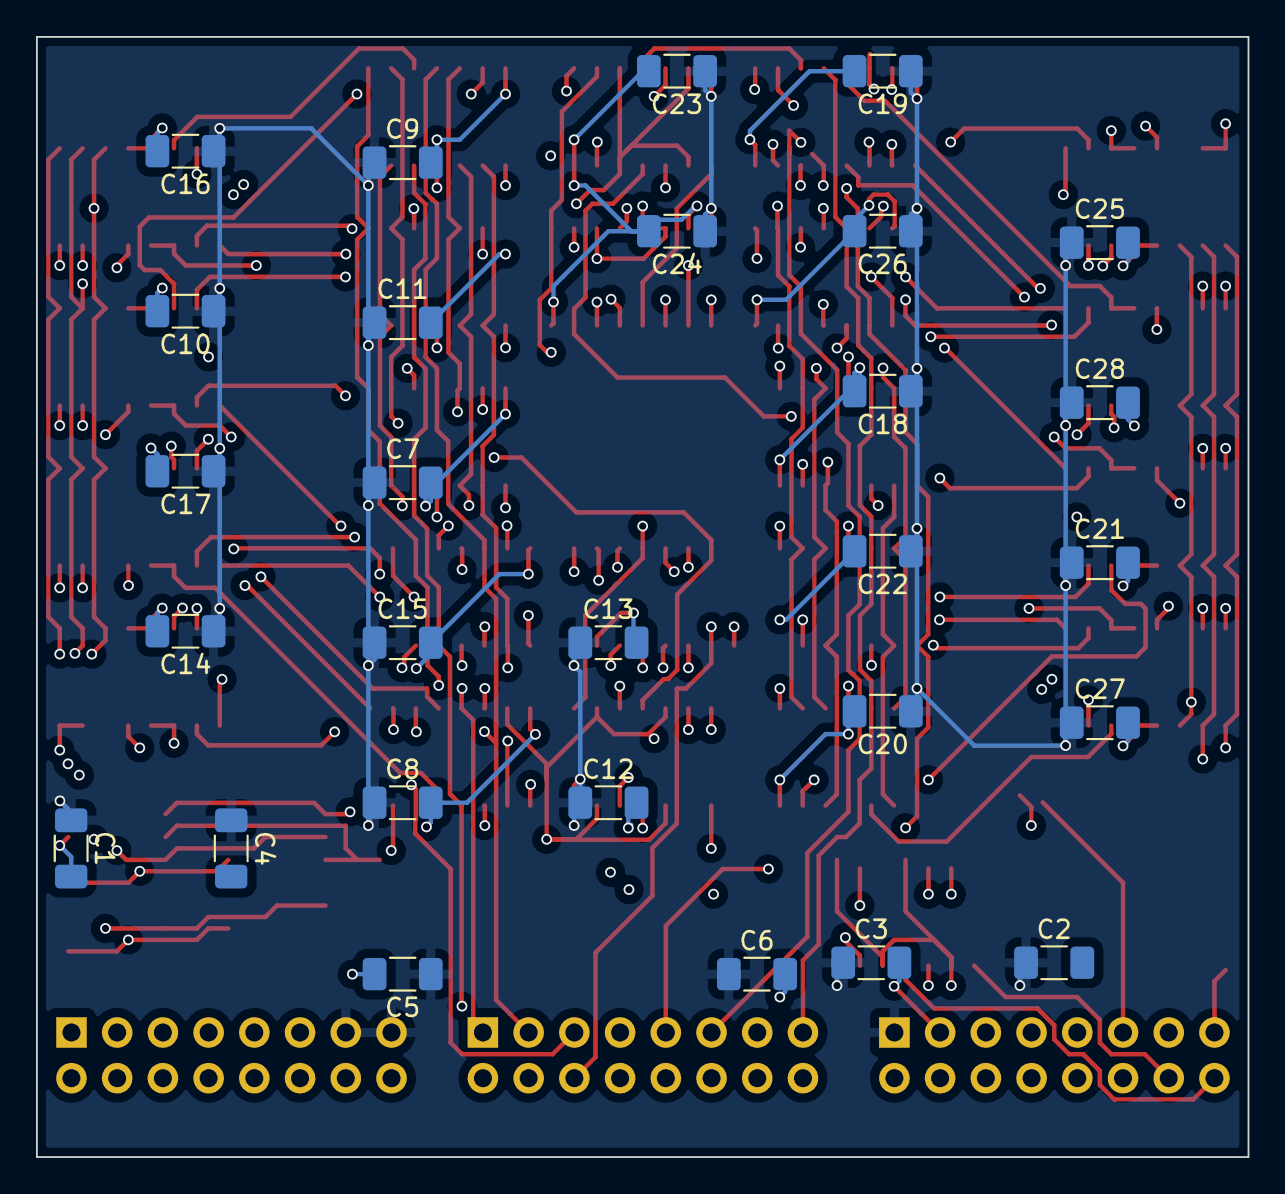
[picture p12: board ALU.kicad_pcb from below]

Board: 4 copper layers, 67.3 x 62.2 mm, 57 parts (28 on the bottom side), 109 nets.

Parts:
C1, C2, C3, C4, C5, C6, C7, C8, C9, C10, C11, C12, C13, C14, C15, C16, C17, C18, C19, C20, C21, C22, C23, C24, C25, C26, C27, C28: .1uF; C_1206_3216Metric_Pad1.33x1.80mm_HandSolder
J1, J2, J3: connector_2x8; PinHeader_2x08_P2.54mm_Horizontal
U2MUX1, U2MUX2, U2MUX3, U2MUX4, U2MUX5, U2MUX6: 74x157; D_R-PDSO-G16
U8MUX1, U8MUX2, U8MUX3, U8MUX4, U8MUX5, U8MUX6, U8MUX7, U8MUX8: 74x151; D_R-PDSO-G16
UADD1, UADD2: 74x283; D_R-PDSO-G16
UAND1, UAND3, UAND4: 74x08; D_R-PDSO-G14
UOR2, UOR3: 74x32; D_R-PDSO-G14
UREG1: 74x377; ON-SOIC20-WB
UXOR2, UXOR3, UXOR4, UXOR5: 74x86; D_R-PDSO-G14

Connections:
/CARRY_BETWEEN: UADD1.9 (C4), UADD2.7 (C0)
/CHANGEOUT: J1.5, UAND1.1, UAND1.4, UAND1.9, UAND1.12
/CLK: J1.15, UREG1.11 (CP)
/IN_ACC0: J2.1, U2MUX4.3 (I1a), UADD1.5 (A1), UAND3.1, UOR2.1, UXOR3.1
/IN_ACC1: J2.3, U2MUX4.6 (I1b), UADD1.3 (A2), UAND3.4, UOR2.4, UXOR3.4
/IN_ACC2: J2.5, U2MUX4.10 (I1c), UADD1.14 (A3), UAND3.9, UOR2.9, UXOR3.9
/IN_ACC3: J2.7, U2MUX4.13 (I1d), UADD1.12 (A4), UAND3.12, UOR2.12, UXOR3.12
/IN_ACC4: J2.9, U2MUX6.3 (I1a), UADD2.5 (A1), UAND4.1, UOR3.1, UXOR5.1
/IN_ACC5: J2.11, U2MUX6.6 (I1b), UADD2.3 (A2), UAND4.4, UOR3.4, UXOR5.4
/IN_ACC6: J2.13, U2MUX6.10 (I1c), UADD2.14 (A3), UAND4.9, UOR3.9, UXOR5.9
/IN_ACC7: J2.15, U2MUX6.13 (I1d), UADD2.12 (A4), UAND4.12, UOR3.12, UXOR5.12
/IN_IMMEDIATE0: J1.2, U2MUX3.2 (I0a), UAND1.2
/IN_IMMEDIATE1: J1.4, U2MUX3.5 (I0b), UAND1.5
/IN_IMMEDIATE2: J1.6, U2MUX3.11 (I0c), UAND1.10
/IN_IMMEDIATE3: J1.8, U2MUX3.14 (I0d), UAND1.13
/IN_OPCODE0: J3.7, U2MUX3.1 (S), U2MUX4.1 (S), U2MUX5.1 (S), U2MUX6.1 (S)
/IN_OPCODE1: J3.5, U8MUX1.11 (S0), U8MUX2.11 (S0), U8MUX3.11 (S0), U8MUX4.11 (S0), U8MUX5.11 (S0), U8MUX6.11 (S0), U8MUX7.11 (S0), U8MUX8.11 (S0), UADD1.7 (C0), UXOR2.2, UXOR2.5, UXOR2.10, UXOR2.13, UXOR4.2, UXOR4.5, UXOR4.10, UXOR4.13
/IN_OPCODE2: J3.3, U2MUX5.2 (I0a), U2MUX5.5 (I0b), U2MUX5.11 (I0c), U2MUX5.14 (I0d), U8MUX1.10 (S1), U8MUX2.10 (S1), U8MUX3.10 (S1), U8MUX4.10 (S1), U8MUX5.10 (S1), U8MUX6.10 (S1), U8MUX7.10 (S1), U8MUX8.10 (S1)
/IN_OPCODE3: J3.1, U8MUX1.9 (S2), U8MUX2.9 (S2), U8MUX3.9 (S2), U8MUX4.9 (S2), U8MUX5.9 (S2), U8MUX6.9 (S2), U8MUX7.9 (S2), U8MUX8.9 (S2)
/IN_REGDATA0: J2.2, U2MUX3.3 (I1a), U2MUX4.2 (I0a)
/IN_REGDATA1: J2.4, U2MUX3.6 (I1b), U2MUX4.5 (I0b)
/IN_REGDATA2: J2.6, U2MUX3.10 (I1c), U2MUX4.11 (I0c)
/IN_REGDATA3: J2.8, U2MUX3.13 (I1d), U2MUX4.14 (I0d)
/IN_REGDATA4: J2.10, U2MUX5.3 (I1a), U2MUX6.2 (I0a)
/IN_REGDATA5: J2.12, U2MUX5.6 (I1b), U2MUX6.5 (I0b)
/IN_REGDATA6: J2.14, U2MUX5.10 (I1c), U2MUX6.11 (I0c)
/IN_REGDATA7: J2.16, U2MUX5.13 (I1d), U2MUX6.14 (I0d)
/OUT_CARRY: J1.11, UREG1.2 (Q0)
/OUT_RESULT0: J3.16, U2MUX1.4 (Za)
/OUT_RESULT1: J3.14, U2MUX1.7 (Zb)
/OUT_RESULT2: J3.12, U2MUX1.9 (Zc)
/OUT_RESULT3: J3.10, U2MUX1.12 (Zd)
/OUT_RESULT4: J3.8, U2MUX2.4 (Za)
/OUT_RESULT5: J3.6, U2MUX2.7 (Zb)
/OUT_RESULT6: J3.4, U2MUX2.9 (Zc)
/OUT_RESULT7: J3.2, U2MUX2.12 (Zd)
/OUT_RX_ID0: J1.10, UAND1.3
/OUT_RX_ID1: J1.12, UAND1.6
/OUT_RX_ID2: J1.14, UAND1.8
/OUT_RX_ID3: J1.16, UAND1.11
/PRESWAPPED0: U2MUX1.2 (I0a), U2MUX2.3 (I1a), U8MUX1.5 (Q)
/PRESWAPPED1: U2MUX1.5 (I0b), U2MUX2.6 (I1b), U8MUX2.5 (Q)
/PRESWAPPED2: U2MUX1.11 (I0c), U2MUX2.10 (I1c), U8MUX3.5 (Q)
/PRESWAPPED3: U2MUX1.14 (I0d), U2MUX2.13 (I1d), U8MUX4.5 (Q)
/PRESWAPPED4: U2MUX1.3 (I1a), U2MUX2.2 (I0a), U8MUX5.5 (Q)
/PRESWAPPED5: U2MUX1.6 (I1b), U2MUX2.5 (I0b), U8MUX6.5 (Q)
/PRESWAPPED6: U2MUX1.10 (I1c), U2MUX2.11 (I0c), U8MUX7.5 (Q)
/PRESWAPPED7: U2MUX1.13 (I1d), U2MUX2.14 (I0d), U8MUX8.5 (Q)
/SWAP_NIBBLES: J1.9, U2MUX1.1 (S), U2MUX2.1 (S)
/lower/OP0_BIT0: U8MUX1.3 (I1), U8MUX1.4 (I0), UADD1.4 (S1)
/lower/OP0_BIT1: U8MUX2.3 (I1), U8MUX2.4 (I0), UADD1.1 (S2)
/lower/OP0_BIT2: U8MUX3.3 (I1), U8MUX3.4 (I0), UADD1.13 (S3)
/lower/OP0_BIT3: U8MUX4.3 (I1), U8MUX4.4 (I0), UADD1.10 (S4)
/lower/OP2_BIT0: U8MUX1.2 (I2), UAND3.3
/lower/OP2_BIT1: U8MUX2.2 (I2), UAND3.6
/lower/OP2_BIT2: U8MUX3.2 (I2), UAND3.8
/lower/OP2_BIT3: U8MUX4.2 (I2), UAND3.11
/lower/OP3_BIT0: U2MUX4.4 (Za), U8MUX1.1 (I3)
/lower/OP3_BIT1: U2MUX4.7 (Zb), U8MUX2.1 (I3)
/lower/OP3_BIT2: U2MUX4.9 (Zc), U8MUX3.1 (I3)
/lower/OP3_BIT3: U2MUX4.12 (Zd), U8MUX4.1 (I3)
/lower/OP4_BIT0: U8MUX1.15 (I4), UOR2.3
/lower/OP4_BIT1: U8MUX2.15 (I4), UOR2.6
/lower/OP4_BIT2: U8MUX3.15 (I4), UOR2.8
/lower/OP4_BIT3: U8MUX4.15 (I4), UOR2.11
/lower/OP5_BIT0: U8MUX1.14 (I5), UXOR3.3
/lower/OP5_BIT1: U8MUX2.14 (I5), UXOR3.6
/lower/OP5_BIT2: U8MUX3.14 (I5), UXOR3.8
/lower/OP5_BIT3: U8MUX4.14 (I5), UXOR3.11
/lower/OPERANDB0: U2MUX3.4 (Za), UAND3.2, UOR2.2, UXOR2.1, UXOR3.2
/lower/OPERANDB1: U2MUX3.7 (Zb), UAND3.5, UOR2.5, UXOR2.4, UXOR3.5
/lower/OPERANDB2: U2MUX3.9 (Zc), UAND3.10, UOR2.10, UXOR2.9, UXOR3.10
/lower/OPERANDB3: U2MUX3.12 (Zd), UAND3.13, UOR2.13, UXOR2.12, UXOR3.13
/upper/CARRY_OUT: UADD2.9 (C4), UREG1.3 (D0)
/upper/OP0_BIT0: U8MUX5.3 (I1), U8MUX5.4 (I0), UADD2.4 (S1)
/upper/OP0_BIT1: U8MUX6.3 (I1), U8MUX6.4 (I0), UADD2.1 (S2)
/upper/OP0_BIT2: U8MUX7.3 (I1), U8MUX7.4 (I0), UADD2.13 (S3)
/upper/OP0_BIT3: U8MUX8.3 (I1), U8MUX8.4 (I0), UADD2.10 (S4)
/upper/OP2_BIT0: U8MUX5.2 (I2), UAND4.3
/upper/OP2_BIT1: U8MUX6.2 (I2), UAND4.6
/upper/OP2_BIT2: U8MUX7.2 (I2), UAND4.8
/upper/OP2_BIT3: U8MUX8.2 (I2), UAND4.11
/upper/OP3_BIT0: U2MUX6.4 (Za), U8MUX5.1 (I3)
/upper/OP3_BIT1: U2MUX6.7 (Zb), U8MUX6.1 (I3)
/upper/OP3_BIT2: U2MUX6.9 (Zc), U8MUX7.1 (I3)
/upper/OP3_BIT3: U2MUX6.12 (Zd), U8MUX8.1 (I3)
/upper/OP4_BIT0: U8MUX5.15 (I4), UOR3.3
/upper/OP4_BIT1: U8MUX6.15 (I4), UOR3.6
/upper/OP4_BIT2: U8MUX7.15 (I4), UOR3.8
/upper/OP4_BIT3: U8MUX8.15 (I4), UOR3.11
/upper/OP5_BIT0: U8MUX5.14 (I5), UXOR5.3
/upper/OP5_BIT1: U8MUX6.14 (I5), UXOR5.6
/upper/OP5_BIT2: U8MUX7.14 (I5), UXOR5.8
/upper/OP5_BIT3: U8MUX8.14 (I5), UXOR5.11
/upper/OPERANDB0: U2MUX5.4 (Za), UAND4.2, UOR3.2, UXOR4.1, UXOR5.2
/upper/OPERANDB1: U2MUX5.7 (Zb), UAND4.5, UOR3.5, UXOR4.4, UXOR5.5
/upper/OPERANDB2: U2MUX5.9 (Zc), UAND4.10, UOR3.10, UXOR4.9, UXOR5.10
/upper/OPERANDB3: U2MUX5.12 (Zd), UAND4.13, UOR3.13, UXOR4.12, UXOR5.13
/~CARRY_WE: J1.7, UREG1.1 (~E)
GND: C1.2, C2.2, C3.2, C4.2, C5.2, C6.2, C7.2, C8.2, C9.2, C10.2, C11.2, C12.2, C13.2, C14.2, C15.2, C16.2, C17.2, C18.2, C19.2, C20.2, C21.2, C22.2, C23.2, C24.2, C25.2, C26.2, C27.2, C28.2, J1.3, J1.13, J3.9, J3.11, U2MUX1.8 (GND), U2MUX1.15 (E), U2MUX2.8 (GND), U2MUX2.15 (E), U2MUX3.8 (GND), U2MUX3.15 (E), U2MUX4.8 (GND), U2MUX4.15 (E), U2MUX5.8 (GND), U2MUX5.15 (E), U2MUX6.8 (GND), U2MUX6.15 (E), U8MUX1.7 (~E), U8MUX1.8 (GND), U8MUX1.12 (I7), U8MUX1.13 (I6), U8MUX2.7 (~E), U8MUX2.8 (GND), U8MUX2.12 (I7), U8MUX2.13 (I6), U8MUX3.7 (~E), U8MUX3.8 (GND), U8MUX3.12 (I7), U8MUX3.13 (I6), U8MUX4.7 (~E), U8MUX4.8 (GND), U8MUX4.12 (I7), U8MUX4.13 (I6), U8MUX5.7 (~E), U8MUX5.8 (GND), U8MUX5.12 (I7), U8MUX5.13 (I6), U8MUX6.7 (~E), U8MUX6.8 (GND), U8MUX6.12 (I7), U8MUX6.13 (I6), U8MUX7.7 (~E), U8MUX7.8 (GND), U8MUX7.12 (I7), U8MUX7.13 (I6), U8MUX8.7 (~E), U8MUX8.8 (GND), U8MUX8.12 (I7), U8MUX8.13 (I6), UADD1.8 (GND), UADD2.8 (GND), UAND1.7 (GND), UAND3.7 (GND), UAND4.7 (GND), UOR2.7 (GND), UOR3.7 (GND), UREG1.4 (D1), UREG1.7 (D2), UREG1.8 (D3), UREG1.10 (GND), UREG1.13 (D4), UREG1.14 (D5), UREG1.17 (D6), UREG1.18 (D7), UXOR2.7 (GND), UXOR3.7 (GND), UXOR4.7 (GND), UXOR5.7 (GND)
unnamed: UADD1.2 (B2), UXOR2.6
unnamed: UADD1.6 (B1), UXOR2.3
unnamed: UADD1.11 (B4), UXOR2.11
unnamed: UADD1.15 (B3), UXOR2.8
unnamed: UADD2.2 (B2), UXOR4.6
unnamed: UADD2.6 (B1), UXOR4.3
unnamed: UADD2.11 (B4), UXOR4.11
unnamed: UADD2.15 (B3), UXOR4.8
VCC: C1.1, C2.1, C3.1, C4.1, C5.1, C6.1, C7.1, C8.1, C9.1, C10.1, C11.1, C12.1, C13.1, C14.1, C15.1, C16.1, C17.1, C18.1, C19.1, C20.1, C21.1, C22.1, C23.1, C24.1, C25.1, C26.1, C27.1, C28.1, J1.1, J3.13, J3.15, U2MUX1.16 (VCC), U2MUX2.16 (VCC), U2MUX3.16 (VCC), U2MUX4.16 (VCC), U2MUX5.16 (VCC), U2MUX6.16 (VCC), U8MUX1.16 (VCC), U8MUX2.16 (VCC), U8MUX3.16 (VCC), U8MUX4.16 (VCC), U8MUX5.16 (VCC), U8MUX6.16 (VCC), U8MUX7.16 (VCC), U8MUX8.16 (VCC), UADD1.16 (VCC), UADD2.16 (VCC), UAND1.14 (VCC), UAND3.14 (VCC), UAND4.14 (VCC), UOR2.14 (VCC), UOR3.14 (VCC), UREG1.20 (VCC), UXOR2.14 (VCC), UXOR3.14 (VCC), UXOR4.14 (VCC), UXOR5.14 (VCC)

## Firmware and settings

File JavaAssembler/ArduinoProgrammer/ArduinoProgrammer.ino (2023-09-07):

#define ADDR_SIZE 15
#define DATA_SIZE 8

const uint8_t PIN_ROM_ADDR[ADDR_SIZE] = {
  28,34,26,36,24,32,29,22,27,35,38,31,30,25,23//forwards (correct)
  //23,25,30,31,38,35,27,22,29,32,24,36,26,34,28//backwards
  //34,26,36,24,32,29,22,27,35,38,31,30,25,23,28//shift one
};

const uint8_t PIN_ROM_DATA[DATA_SIZE] = {
  52,50,51,44,48,42,40,46
};

const uint8_t PIN_NWE = 33;// Not Write  Enable
const uint8_t PIN_NCE = 39;// Not Chip   Enable
const uint8_t PIN_NOE = 37;// Not Output Enable

void disableROM() {
  digitalWrite(PIN_NWE,true);
  digitalWrite(PIN_NCE,true);
  digitalWrite(PIN_NOE,true);
}

void setAddress(uint16_t address) {
  for (uint8_t i=0; i<ADDR_SIZE; i++) {
    digitalWrite(PIN_ROM_ADDR[i],0b1 & (address>>i));
  }
}

void setData(uint8_t data) {
  for (uint8_t i=0; i<DATA_SIZE; i++) {
    digitalWrite(PIN_ROM_DATA[i],0b1 & (data>>i));
  }
}

uint8_t getData() {
  uint8_t ret = 0;
  for (uint8_t i=0;i<DATA_SIZE;i++) {
    uint8_t b = digitalRead(PIN_ROM_DATA[i])?1:0;
    ret |= b<<i;
  }
  return ret;
}

#include "hex.h"

void programWriteAddrData(uint16_t addr, uint8_t data) {
  setAddress(addr);
  setData(data);
  asm("nop");asm("nop");asm("nop");asm("nop");
  asm("nop");asm("nop");asm("nop");asm("nop");
  digitalWrite(PIN_NWE,false);//Latch addr
  asm("nop");asm("nop");asm("nop");asm("nop");
  asm("nop");asm("nop");asm("nop");asm("nop");
  digitalWrite(PIN_NWE,true);//Latch data
  for (long i=0;i<40000L;i++) asm("nop");
  
  asm("nop");asm("nop");asm("nop");asm("nop");
}

void programROM() {
  disableROM();
  Serial.println("Programming ROM");
  for (int i=0;i<DATA_SIZE;i++) pinMode(PIN_ROM_DATA[i],OUTPUT);
  
  Serial.print("Program Size:");
  Serial.print(PROGSIZE);Serial.println(" bytes.");
  digitalWrite(PIN_NCE,false);//Enable Chip
  // Using byte write method
  for (uint16_t addr=0; addr<PROGSIZE; addr++) {
    programWriteAddrData(addr,pgm_read_byte_near(PROG+addr));
  }
  disableROM();
  Serial.println("Programming Done!");
}

boolean verifyROM() {  
  boolean isBad = false;
  Serial.println("Verify ROM");
  for (int i=0;i<DATA_SIZE;i++) pinMode(PIN_ROM_DATA[i],INPUT);
  
  digitalWrite(PIN_NWE,true);
  digitalWrite(PIN_NCE,false);
  digitalWrite(PIN_NOE,false);
  for (uint16_t addr=0; addr<PROGSIZE; addr++) {
    setAddress(addr);
    asm("nop");asm("nop");asm("nop");asm("nop");
    for (int x=0;x<16;x++) asm("nop");asm("nop");asm("nop");asm("nop");
    uint8_t data = getData();
    
    if (pgm_read_byte_near(PROG+addr) != data) {
      isBad=true;
      Serial.print("BAD:");Serial.print(pgm_read_byte_near(PROG+addr),BIN);
      Serial.print(" != ");
    }
    Serial.print("ROM[0x");Serial.print(addr,HEX);
    Serial.print("] = 0x");Serial.print(data,HEX);
    Serial.print(" = 0b");Serial.print(data,BIN);
    Serial.println("");
    
  }
  disableROM();
  return isBad;
}

void softwareEraseROM() {
  // https://ww1.microchip.com/downloads/en/Appnotes/doc0544.pdf
  Serial.println("Clear ROM");
  
  digitalWrite(PIN_NCE,false);//Enable Chip
  programWriteAddrData(0xAAAAL, 0xAA);
  programWriteAddrData(0x5554L, 0x55);
  programWriteAddrData(0xAAAAL, 0x80);
  programWriteAddrData(0xAAAAL, 0xAA);
  programWriteAddrData(0x5554L, 0x55);
  programWriteAddrData(0xAAAAL, 0x10);
  
  /*programWriteAddrData(0x5555L, 0xAA);
  programWriteAddrData(0x2AAAL, 0x55);
  programWriteAddrData(0x5555L, 0x80);
  programWriteAddrData(0x5555L, 0xAA);
  programWriteAddrData(0x2AAAL, 0x55);
  programWriteAddrData(0x5555L, 0x10);*/
  //wait 20ms: 20MHz × 20ms = 400E3
  for (long i=0;i<400000L;i++) {
    asm("nop");
  }
  disableROM();
}

void setup() {
  //Verify right image
  Serial.begin(115200);
  Serial.print("\n\n\nType ");Serial.print(PROGNAME);Serial.println("to program it.");
  while (true) {
    String line = Serial.readString();
    line.trim();
    if (line==PROGNAME) break;
  }
  Serial.print("STARTING ");Serial.println(PROGNAME);

  for (int i=0;i<ADDR_SIZE;i++) pinMode(PIN_ROM_ADDR[i],OUTPUT);
  pinMode(PIN_NWE,OUTPUT);
  pinMode(PIN_NCE,OUTPUT);
  pinMode(PIN_NOE,OUTPUT);
  disableROM();

  //softwareEraseROM();
  
  verifyROM();  
  programROM();
  verifyROM();
  verifyROM();
  Serial.println("Done.\n\n");
}

void loop() {}

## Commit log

2022-02-20 End of Repeat With Carry
    My last bit of documentation before asking on stackoverflow (https://stackoverflow.com/questions/71188654/would-an-instruction-set-architecture-benefit-from-both-an-adc-and-sbc-or-could/71188757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)
    and realizing that doing a skip-if would be much better and more versatile than a simple rwc.
2022-02-20 Improving computer - Added conditional skip instruction. This takes the place of carry, skip, rotate, and many other instructions.
    Currently working on simplifying assembler.
2022-04-27 Starting hardware! Also currently moving ProgramCounter logic into a LogiSim module to abstract it better
    [16bitadder.sch, ProgramCounter.kicad_pcb, ProgramCounter.sch]
2022-04-27 Started to make Schematic for the Program Counter.
    TODO: Complete schematic, buy parts, layout PCB, solder PCB.
    Then logically test the PCB using a digital oscilloscope.
    Then repeat for 4-5 other PCBs.
    [16bitadder.sch, 16x2to1Mux.sch, ProgramCounter.sch]
2022-04-29 PC PCB Progress
    Mostly done with schematic for the Program Counter. I'll order parts soon and start on the PCB design next. It'll be my first four layer board!
    Based on what I've seen so far, CMOS seems to be more prevalent than TTL, so I'll make this computer out of CMOS.
    [16bitadder.sch, 16x2to1Mux.sch, ProgramCounter.kicad_pcb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]
2022-05-04 PC Schematic
    Mostly finished Program Counter schematic. I'm basing the hardware largely off of TI's new HCS family of SN74HCS chips.
    [16bitadder.sch, 16x2to1Mux.sch, ProgramCounter.kicad_pcb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]
2022-05-09 PC Board
    Mostly done. Going to move top half down.
    [16bitadder.sch, 16x2to1Mux.sch, ProgramCounter.kicad_pcb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]
2022-05-10 PC Board
    Mostly done. Going to move register to the right and connect logic gates
    [ProgramCounter.kicad_pcb, ProgramCounter.sch]
2022-05-12 Program Counter Board
    Seems to be done. Likely be ordering very soon. Also added a debug/testpoint connector to the top so that I can probe it easier
    [ProgramCounter-B_Cu.gbr, ProgramCounter-B_Mask.gbr, ProgramCounter-B_Paste.gbr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]
2022-05-12 Register File Board
    Starting out the general layout
    [RegisterFile.kicad_pcb, RegisterFile.sch]
2022-05-21 Created export for Program Counter PCB V1
    [ProgramCounter-B_Cu.gbr, ProgramCounter-B_Mask.gbr, ProgramCounter-B_Paste.gbr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]
2022-06-25 Making Register File board in Kicad6
    [RegisterFile.kicad_pcb, RegisterFile.kicad_sch, RegisterFile.sch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]
2022-06-25 RegisterFile Layout: Everything except the "spider" (routing the all 8 muxes each to all 8 registers might be non-trivial)
    [RegisterFile.kicad_pcb, RegisterFile.kicad_sch, regs.kicad_sch]
2022-06-26 RegisterFile: The layout's all done!
    [RegisterFile-B_Cu.gbr, RegisterFile-B_Mask.gbr, RegisterFile-B_Paste.gbr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]
2022-07-08 ALU Schematic: Mostly done!
    [ALU.kicad_pcb, ALU.kicad_sch, operators.kicad_sch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]
2022-07-12 ALU Schematic: A backup save before I realized Kicad doesn't seem to officially support hierarchical busses. Soon to replace all sheet busses with lines (I guess four lines isn't too many...)
    [ALU.kicad_pcb, ALU.kicad_sch, operators.kicad_sch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]
2022-07-16 ALU: About to increase modularity by moving opcode parsing out of ALU onto motherboard (would turn backplane into more of a motherboard).
    [ALU.kicad_pcb, ALU.kicad_sch, operators.kicad_sch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]
2022-07-16 ALU: Starting routing. Also passing this to kicad's github #collab
    [ALU.kicad_pcb, ALU.kicad_sch, operators.kicad_sch]
2022-07-17 ALU: Routing Progress
    [ALU.kicad_pcb]
2022-07-19 Logisim: Saving before replacing ALU with mux-based-alu and before replacing von-neumann-based memory with harvard-based memory
    [ALU.kicad_pcb]
2022-07-21 Logisim: count.asm working well! Going to make MuxALU schematic now.
    [ALUMux.kicad_pcb, ALUMux.kicad_sch]
2022-07-28 ALUMux: Progress on routing/layout
    [ALUMux.kicad_pcb, ALUMux.kicad_sch, RegisterFile.kicad_pcb]
2022-07-30 ALUMux: PCB done.
    Going to start ProgramCounter2
    [ALUMux-B_Cu.gbr, ALUMux-B_Mask.gbr, ALUMux-B_Paste.gbr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]
2022-10-24 Motherboard Significant Progress
    This involves significant buildup of the motherboard, such as the power, oscillator, and overall design.
    The motherboard schematic is in progress (some lines have yet to be connected), and the PCB layout is mostly just there to consider spacing.
    [16bitadder.kicad_sch, 16x2to1Mux.kicad_sch, ALUMux.kicad_sch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]
2022-11-06 Switch the compiler to Java
    [Motherboard.kicad_sch, daughterboards.kicad_sch]
2023-03-19 Motherboard Schematic Major Updates: - Skip implemented - Memory WB implemented Also, the JavaAssembler was somewhat updated but isn't done yet.
    [ALUMux.kicad_pcb, Motherboard.kicad_sch, daughterboards.kicad_sch]
2023-03-29 Motherboard Layout: Most Traces Done
    ~30 traces left for motherboard, then it's all ready for ordering!
    [Motherboard.kicad_sch, parts.ignore.ods]
2023-03-29 Motherboard V1
    [Motherboard-B_Cu.gbr, Motherboard-B_Mask.gbr, Motherboard-B_Paste.gbr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]
2023-04-04 Motherboard V1.1
    With teardrops and other small changes
    [Motherboard-B_Cu.gbr, Motherboard-B_Mask.gbr, Motherboard-B_Paste.gbr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]
2023-09-03 Java compiler paired with Arduino ROM programmer. Arduino ROM programmer fully functional.
